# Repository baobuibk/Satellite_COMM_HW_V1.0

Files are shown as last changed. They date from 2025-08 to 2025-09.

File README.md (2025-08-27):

# Dự án COMM_BOARD - Satellite_COMM_HW_V1.0

## Giới thiệu
Dự án `COMM_BOARD` là một phần của hệ thống phần cứng giao tiếp vệ tinh (`Satellite_COMM_HW_V1.0`), được thiết kế trên **Altium Designer**. Bo mạch này hỗ trợ giao tiếp dữ liệu cho ứng dụng vệ tinh, bao gồm truyền nhận tín hiệu RF và giao tiếp với các thiết bị ngoại vi, sử dụng vi điều khiển STM32H745.

## Cấu trúc thư mục
```
├── 01_DESIGN/                # Tệp thiết kế chính
├── 02_Schematic_pdf/         # Sơ đồ mạch dưới dạng PDF
├── 03_BOM/                   # Danh sách linh kiện (Bill of Materials)
├── 04_GERBER/                # Tệp Gerber cho sản xuất
├── 05_SMT/                   # Hướng dẫn lắp ráp SMT
├── 06_CAD/                   # Tệp CAD bổ sung
├── 07_REF/                   # Tài liệu tham khảo
├── 08_3D/                    # Mô hình 3D
└── README.md                 # File này
```

## Yêu cầu
- **Phần mềm**: Altium Designer phiên bản 21.0 hoặc mới hơn.
- **Phần cứng**: 
  - Vi điều khiển STM32H745.
  - Các linh kiện khác theo BOM trong `03_BOM/`.
- **Công cụ khác**: Phần mềm lập trình firmware (STM32CubeIDE).

## Hướng dẫn cài đặt
1. **Tải dự án**:
   - Clone repository về máy:
     ```
     git clone https://github.com/baobuibk/Satellite_COMM_HW_V1.0.git
     ```
2. **Mở dự án trong Altium**:
   - Mở Altium Designer.
   - Chọn `File > Open Project` và điều hướng đến thư mục `1_COMM_BOARD`.
   - Mở tệp `.PrjPcb` trong thư mục.

## Hướng dẫn sản xuất
- Xuất Gerber từ thư mục `04_GERBER/` và gửi cho nhà sản xuất.
- Tham khảo `05_SMT/` để lắp ráp linh kiện.
- Kiểm tra thiết kế bằng DRC trong Altium trước khi sản xuất.

## Ghi chú
- Đảm bảo kiểm tra kết nối RF và nguồn điện trước khi sử dụng.
- Tài liệu tham khảo bổ sung có trong `07_REF/`.

## Liên hệ
- Tác giả: [baobuibk]
- GitHub: [https://github.com/baobuibk]

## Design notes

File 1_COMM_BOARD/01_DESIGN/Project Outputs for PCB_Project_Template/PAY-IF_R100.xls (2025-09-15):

Board Stack Report
Stack Up |  | Layer Stack
Layer | Board Layer Stack | Name | Material | Thickness | Constant
1 |  | Top Overlay |  | 0mm
2 |  | Top Solder | Solder Resist | 0.012mm | 3.5
3 |  | Top Layer |  | 0.055mm
4 |  | Dielectric 2 | FR-4 | 0.1mm | 3.9
5 |  | L2_GND | CF-004 | 0.032mm
6 |  | Dielectric 3 |  | 0.11mm | 4.1
7 |  | L3_PWR | CF-004 | 0.032mm
8 |  | Dielectric 1 | FR-4 | 0.94mm | 4.8
9 |  | L4_SIG | CF-004 | 0.032mm
10 |  | Dielectric 4 |  | 0.11mm | 4.1
11 |  | L5_GND | CF-004 | 0.032mm
12 |  | Dielectric 5 | FR-4 | 0.1mm | 3.9
13 |  | Bottom Layer |  | 0.055mm
14 |  | Bottom Solder | Solder Resist | 0.012mm | 3.5
15 |  | Bottom Overlay |  | 0mm
 | Height : 1.622mm

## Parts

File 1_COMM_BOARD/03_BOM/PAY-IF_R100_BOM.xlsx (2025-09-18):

Name | Description | Designator | Quantity | Footprint | Manufacturer | Manufacturer P/N
BT_NRST | SWITCH TACTILE SPST-NO 0.05A 12V | BT1 | 1 | SW2-SMD | C&K Components | PTS636SK25FSMTR LFS
0.1uF/16V | CAP CER 0.1UF 25V X7R 0603 | C1, C2, C3, C4, C5, C6, C7, C8, C9, C10, C11, C12, C13, C14, C15, C16, C17, C18, C19, C20, C21, C24, C27, C28, C30, C31, C32, C34, C58, C59, C60, C61, C62, C63, C64, C65, C66, C67, C68, C69, C71, C72, C73, C74, C75, C76, C77, C78, C79, C80, C90, C91, C94, C96, C97, C98, C99, C100, C101, C103 | 60 | CAP_C_1608X80 | Samsung Electro-Mechanics | CL10B104KA8NNNC
12pF/10V | CAP CER 12PF 50V C0G/NP0 0603 | C22, C23, C25, C26 | 4 | CAP_C_1608X80 | Samsung Electro-Mechanics | CL10C120JB81PNC
2.2uF/10V | CAP CER 2.2UF 10V X7R 0603 | C29, C46, C86, C87 | 4 | CAP_C_1608X80 | Samsung Electro-Mechanics | CL10B225KP8NNNC
1uF/25V | CAP CER 1UF 25V X7R 0603 | C33, C48, C50 | 3 | CAP_C_1608X80 | Samsung Electro-Mechanics | CL10B105KA8NNNC
4.7nF/16V | CAP CER 4700PF 50V X7R 0603 | C35 | 1 | CAP_C_1608X80 | Samsung Electro-Mechanics | CL10B472KB8NNNC
10uF/25V | CAP CER 10UF 25V X5R 0603 | C36, C38, C40, C41, C45, C49 | 6 | CAP_C_1608X80 | Samsung Electro-Mechanics | CL10A106MA8NRNC
1uF/16V | CAP CER 1UF 25V X7R 0603 | C37, C39, C93, C95 | 4 | CAP_C_1608X80 | Samsung Electro-Mechanics | CL10B105KA8NNNC
2.2nF/25V | CAP CER 2200PF 50V X7R 0603 | C42, C43 | 2 | CAP_C_1608X80 | Samsung Electro-Mechanics | CL10B222KB8NNNC
10nF/16V | CAP CER 10000PF 50V X7R 0603 | C44 | 1 | CAP_C_1608X80 | Samsung Electro-Mechanics | CL10B103KB8NNNC
4.7uF/16V | CAP CER 4.7UF 6.3V X7R 0603 | C47, C70, C88, C89, C92 | 5 | CAP_C_1608X80 | Samsung Electro-Mechanics | CL10B475KQ8NQNC
SS54 | DIODE SCHOTTKY 40V 5A SMA | D1 | 1 | DO-214AC_SMA | Multicomp | SS54
BLM18PG121SN1D | FERRITE BEAD 120 OHM 0603 1LN | FB2 | 1 | IND_1608x65 | Murata | BLM18PG121SN1D
ESQ-126-14-G-D | CONN SOCKET 52POS 0.1 GOLD PCB | H1, H2 | 2 | SAMTEC_ESQ-126-14-G-D | Samtec | ESQ-126-14-G-D
hole_space | x | Hole1, Hole2, Hole3, Hole4 | 4 | HOLE_SPACE | x | x
5040500591 | CONN HEADER SMD R/A 5POS 1.5MM | J1 | 1 | 5040500591 | Molex | 504050-0591
532610671 | CONN HEADER SMD R/A 6POS 1.25MM | J1B, J4B | 2 | MOLEX_532610671 | Molex | 53261-0671
5040500991 | CONN HEADER SMD R/A 9POS 1.5MM | J2, J3 | 2 | 5040500991 | Molex | 504050-0991
532610971 | CONN HEADER SMD R/A 9POS 1.25MM | J2B, J3B | 2 | 532610971 | Molex | 53261-0971
5040500691 | CONN HEADER SMD R/A 6POS 1.5MM | J4 | 1 | 5040500691 | Molex | 504050-0691
9159010061911 | CONN SSL RCP | J5 | 1 | 9159010061911 | x | x
61301021121 | CONN HEADER VERT 10POS 2.54MM | J5BK | 1 | 61301021121 | Wurth Elektronik | 61301021121
ZX62R-B-5P(30) | CONN RCPT USB2.0 MICRO B SMD R/A | J6 | 1 | AMPHENOL_GMCB05321121BEU | Hirose Electric Co Ltd | ZX62R-B-5P(30)
SRP7050TA-220M | FIXED IND 22UH 2.5A 170 MOHM SMD | L1 | 1 | SRP7050TA-220M | Bourns | SRP7050TA-220M
150060BS75000 | LED BLUE CLEAR 0603 SMD | LED1 | 1 | LED_0603 | Wurth Elektronik | 150060BS75000
150060GS75000 | LED GREEN CLEAR 0603 SMD | LED2 | 1 | LED_0603 | Wurth Elektronik | 150060GS75000
150060RS75000 | LED RED CLEAR 0603 SMD | LED3, LED4 | 2 | LED_0603 | Wurth Elektronik | 150060RS75000
150060YS75000 | LED YELLOW CLEAR 0603 SMD | LED5 | 1 | LED_0603 | Wurth Elektronik | 150060YS75000
MMBT2222A | BJT, SOT-23, 40V, 600mA, NPN, 0.25W, 150Â°C | Q1 | 1 | SOT95P240X120-3N | Nexperia | MMBT2222A,215
10k | RES SMD 10K OHM 1% 1/10W 0603 | R1, R2, R3, R4, R5, R6, R7, R8, R18, R22, R83, R84, R87, R91, R116, R117, R118, R127 | 18 | RES_C_1608X60 | Panasonic | ERJ-3EKF1002V
22R | RES SMD 22 OHM 1% 1/10W 0603 | R9, R10, R11, R12, R13, R14, R15, R16, R20, R21, R23, R24, R25, R26, R27, R28, R29, R30, R31, R32, R33, R34, R35, R36, R37, R38, R39, R40, R41, R42, R43, R44, R45, R46, R47, R48, R49, R50, R51, R52, R53, R54, R55, R56, R57, R58, R59, R60, R61, R62, R63, R64, R65, R66, R67, R68, R69, R70, R71, R72, R73, R74, R75, R76, R77, R78, R81, R85, R94, R95, R96, R97, R98, R99, R142, R143, R154, R155, R156, R157, R158, R159, R160, R163, R164, R165 | 86 | RES_C_1608X60 | Panasonic | ERJ-3EKF22R0V
47k | RES SMD 47K OHM 1% 1/10W 0603 | R17, R125 | 2 | RES_C_1608X60 | Panasonic | ERJ-3EKF4702V
0R | RES SMD 0 OHM JUMPER 1/10W 0603 | R19, R89, R90, R148, R150 | 5 | RES_C_1608X60 | Panasonic | ERJ-3GEY0R00V
1k | RES SMD 1K OHM 1% 1/10W 0603 | R79, R80, R88, R121, R126 | 5 | RES_C_1608X60 | Panasonic | ERJ-3EKF1001V
10k (DNP) | RES SMD 10K OHM 1% 1/10W 0603 | R82, R86 | 2 | RES_C_1608X60 | Panasonic | ERJ-3EKF1002V
100R (DNP) | RES SMD 100 OHM 1% 1/10W 0603 | R92, R93 | 2 | RES_C_1608X60 | Panasonic | ERJ-3EKF1000V
2.2k | RES SMD 2.2K OHM 1% 1/10W 0603 | R100 | 1 | RES_C_1608X60 | Panasonic | ERJ-3EKF2201V
60R | RES SMD 60.4 OHM 1% 1/10W 0603 | R114, R115 | 2 | RES_C_1608X60 | Panasonic | ERJ-3EKF60R4V
4.7k | RES SMD 4.7K OHM 1% 1/10W 0603 | R119, R151, R152, R153 | 4 | RES_C_1608X60 | Panasonic | ERJ-3EKF4701V
470k | RES SMD 470K OHM 1% 1/10W 0603 | R123 | 1 | RES_C_1608X60 | Panasonic | ERJ-3EKF4703V
11k | RES SMD 11K OHM 1% 1/10W 0603 | R124 | 1 | RES_C_1608X60 | Panasonic | ERJ-3EKF1102V
5.9k | RES SMD 5.9K OHM 1% 1/10W 0603 | R128 | 1 | RES_C_1608X60 | Panasonic | ERJ-3EKF5901V
16.5k | RES SMD 16.5K OHM 1% 1/10W 0603 | R161, R162 | 2 | RES_C_1608X60 | Panasonic | ERJ-3EKF1652V
JUMPER | x | SB1, SB2 | 2 | JUMPER_1608 | x | x
ESDCAN02-2BWY | TVS DIODE 26.5VWM 44VC SOT3233 | TVS2 | 1 | SOT323-3L_STM | STMicroelectronics | ESDCAN02-2BWY
STM32H745XIH6 | IC MCU 32BIT 2MB FLASH TFBGA | U1 | 1 | BGA265C80P17X17_1400X1400X110N | STMicroelectronics | STM32H745XIH6
IS42S32400J-6BL | DRAM 128M, 3.3V, SDRAM, 4Mx32, 166Mhz, 90 ball BGA (8mmx13mm) RoHS | U2 | 1 | BGA90C80P9X15_800X1300X120 | ISSI | IS42S32400J-6BL
MTFC32GAZAQDW-AAT | IC FLASH 32GBIT PAR 100LBGA | U3 | 1 | BGA_100_C_100P_10X17_1400X1800X150 | Micron | MTFC32GAZAQDW-AAT
AS3004204-0108X0PSAY | MRAM Avalanche High Performance Serial P-SRAM 4Mb in SOIC8 package with QSPI - 108MHz interface, 3V, -40 C to 105 C | U4 | 1 | SOIC127P790X216-8N | Avalanche Technology | AS3004204-0108X0PSAY
SN65HVD230DR | IC TRANSCEIVER HALF 1/1 8SOIC | U5 | 1 | SOIC127P599X175-8N | Texas Instruments | SN65HVD230DR
DS90LV011AQ-Q1 | LVDS Interface IC Automotive LVDS diff erential driver | U6, U7 | 2 | DS90LV011AQ-Q1 | Texas Instruments | DS90LV011AQMFE/NOPB
TPS259470ARPWR | IC ELECTRONIC FUSE 10VQFN | U9 | 1 | VQFN-HR-10 | Texas Instruments | TPS259470ARPWR
TPS5430DDAR | IC REG BUCK ADJ 3A 8SOPWR | U10 | 1 | CONV_TPS5430DDAR | Texas Instruments | TPS5430DDAR
IS66WVS4M8BLL-104NLI | IC PSRAM 32MBIT SPI QPI 8SOIC | U14 | 1 | SOIC8_150MIL_N_ISI | ISSI | IS66WVS4M8BLL-104NLI
TPL5010DDCR | IC OSC PROG TIMER TSOT23-6 | U15 | 1 | TPL5010DDCR | Texas Instruments | TPL5010DDCR
TC1047AVNBTR | SENSOR ANALOG -40C-125C SOT23-3 | U16, U17, U18 | 3 | SOT-23_MC_MCH | Microchip | TC1047AVNBTR
ECS-250-12-33Q-JES-TR | CRYSTAL 25.0000MHZ 12PF SMD | X1 | 1 | XTAL_ECS-250-12-33Q-JES-TR | ECS International | ECS-250-12-33Q-JES-TR
XT1312HHRXX32K76E | CRYSTAL, 3.2X1.5MM, 12.5PF LOAD | X2 | 1 | XT1312HHRXX32K76E | Vishay | XT1312HHRXX32K76E
 |  |  | 268

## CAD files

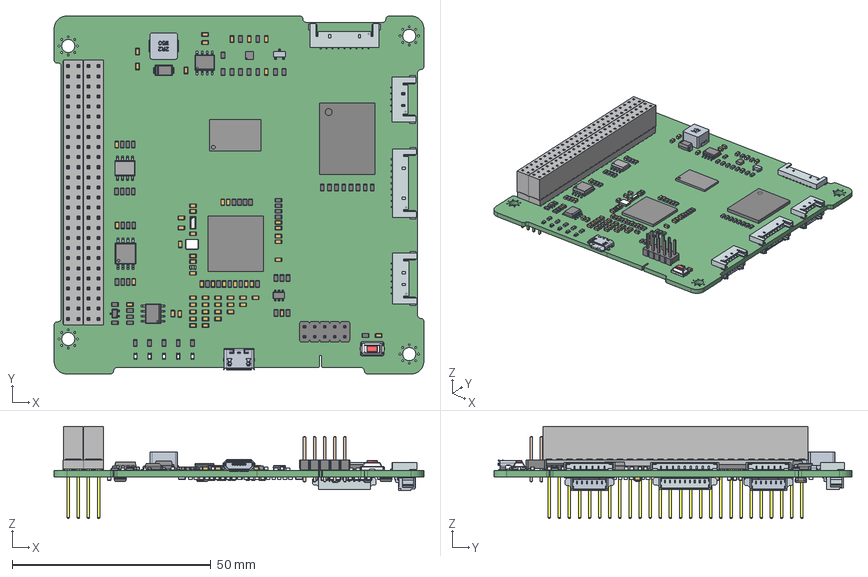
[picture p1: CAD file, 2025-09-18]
1_COMM_BOARD/08_3D/PAY-IF_R100.step
93.0 x 90.0 x 23.2 mm
Mid Body x 132
Mark x 132
housing x 5
cover x 5
base x 10
Polarity Mark x 5
ball x 170
PinsArrayLR
ESQ-126-14-G-D_socket x 2
ESQ-126-14-G-D_pins x 2
ESQ-126-14-G-D2_pins x 2
ESQ-126-14-G-D-LL_bpins x 2
6130xx21121_PIN x 10
XT1312HHRXX32K76E
TPS259470ARPWR
A1
A2
A3
A7
A8
A9
B1
B2
B3
B7
B8
B9
C1
C2
C3
C7
C8
C9
D1
D2
D3
D7
D8
D9
E1
E2
E3
E7
E8
E9
F1
F2
F3
F7
F8
F9
G1
G2
G3
G7
G8
G9
H1
H2
H3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

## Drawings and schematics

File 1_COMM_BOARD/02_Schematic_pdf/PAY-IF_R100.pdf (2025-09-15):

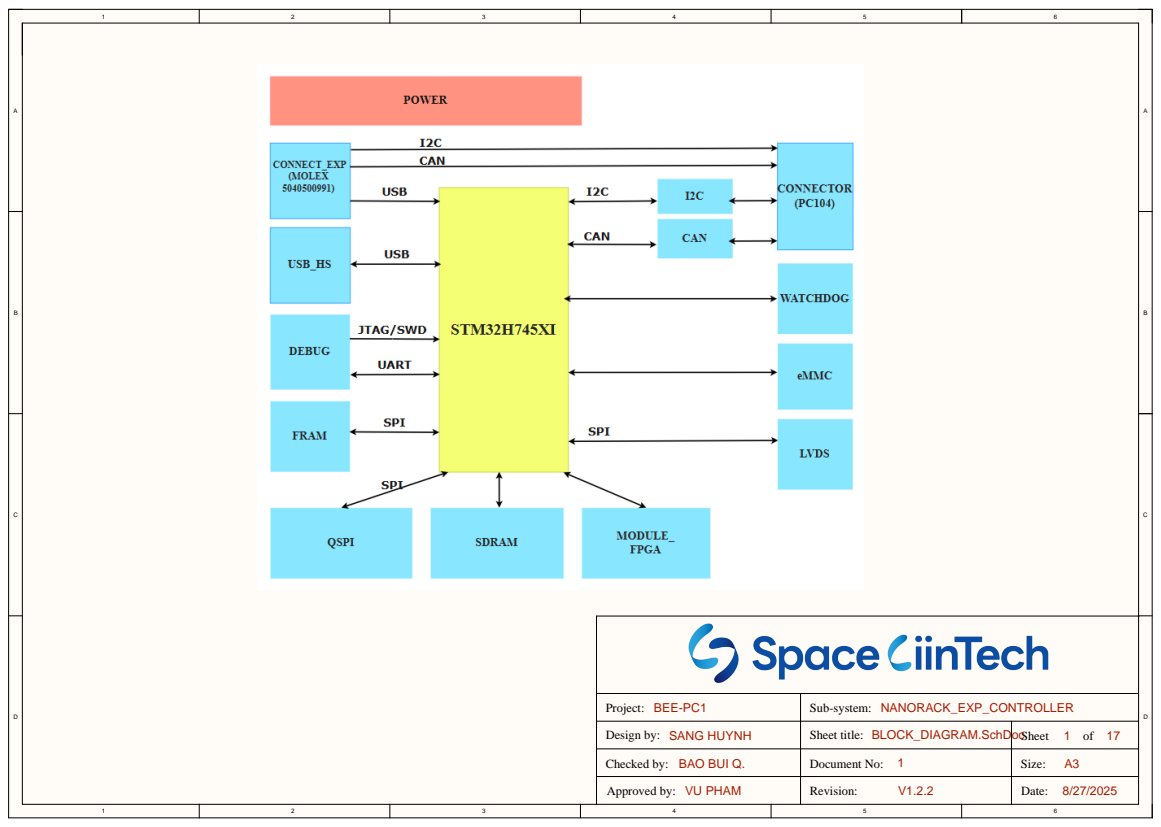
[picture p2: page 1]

Project: BEE-PC1 | Sub-system: NANORACK_EXP_CONTROLLER

Design by: SANG HUYNH | Sheet title: BLOCK_DIAGRAM.SchDoc | Sheet 1 of 17

Checked by: BAO BUI Q. | Document No: 1 | Size: A3

Approved by: VU PHAM | V1.2.2 Revision: | Date: 8/27/2025

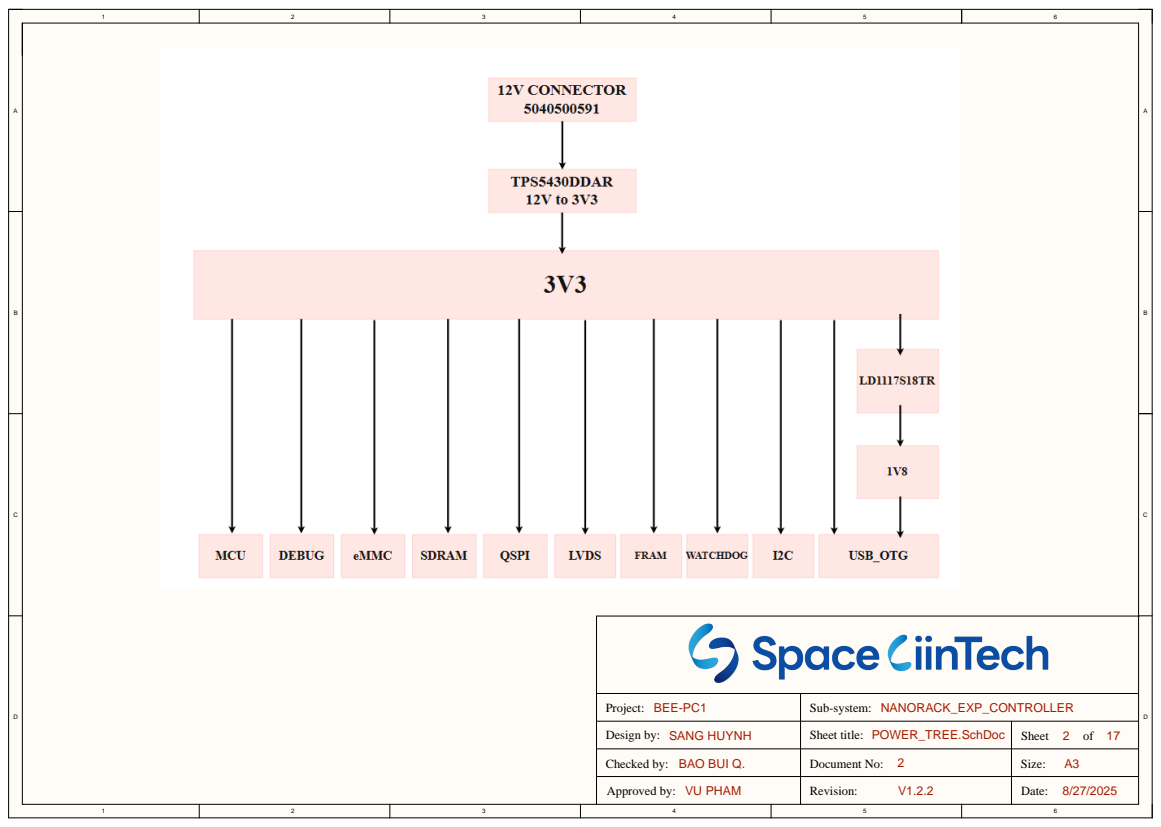
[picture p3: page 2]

Project: BEE-PC1 | Sub-system: NANORACK_EXP_CONTROLLER

Design by: SANG HUYNH | Sheet title: POWER_TREE.SchDoc | Sheet 2 of 17

Checked by: BAO BUI Q. | Document No: 2 | Size: A3

Date: 8/27/2025

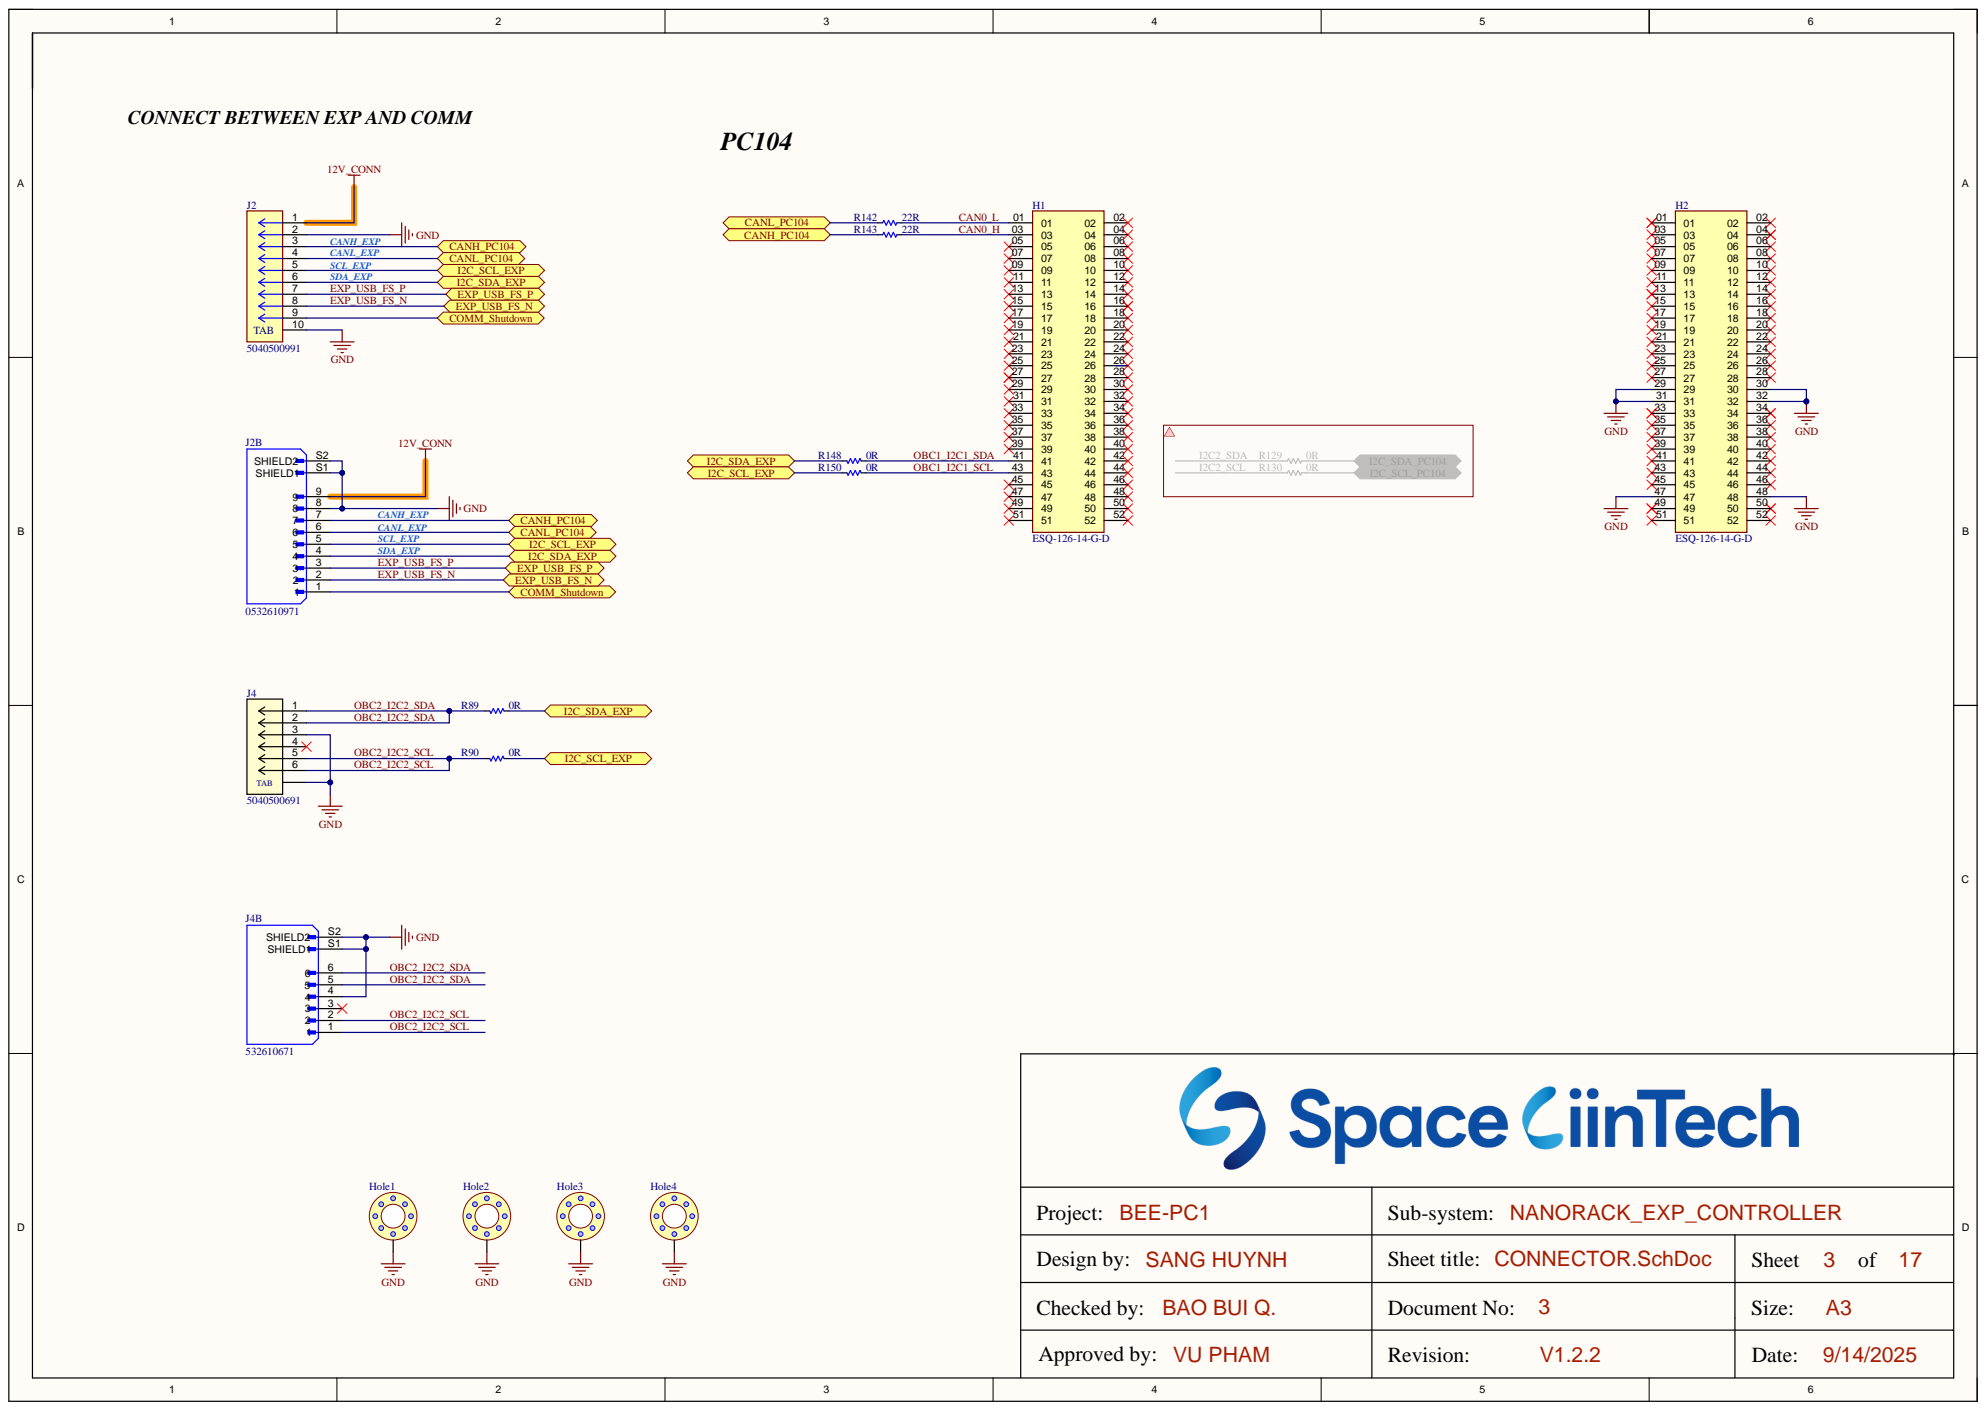
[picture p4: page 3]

CONNECT BETWEEN EXP AND COMM

Project: BEE-PC1 | Sub-system: NANORACK_EXP_CONTROLLER

Design by: SANG HUYNH | Sheet title: CONNECTOR.SchDoc | Sheet 3 of 17

Checked by: BAO BUI Q. | Document No: 3 | Size: A3

Date: 9/14/2025

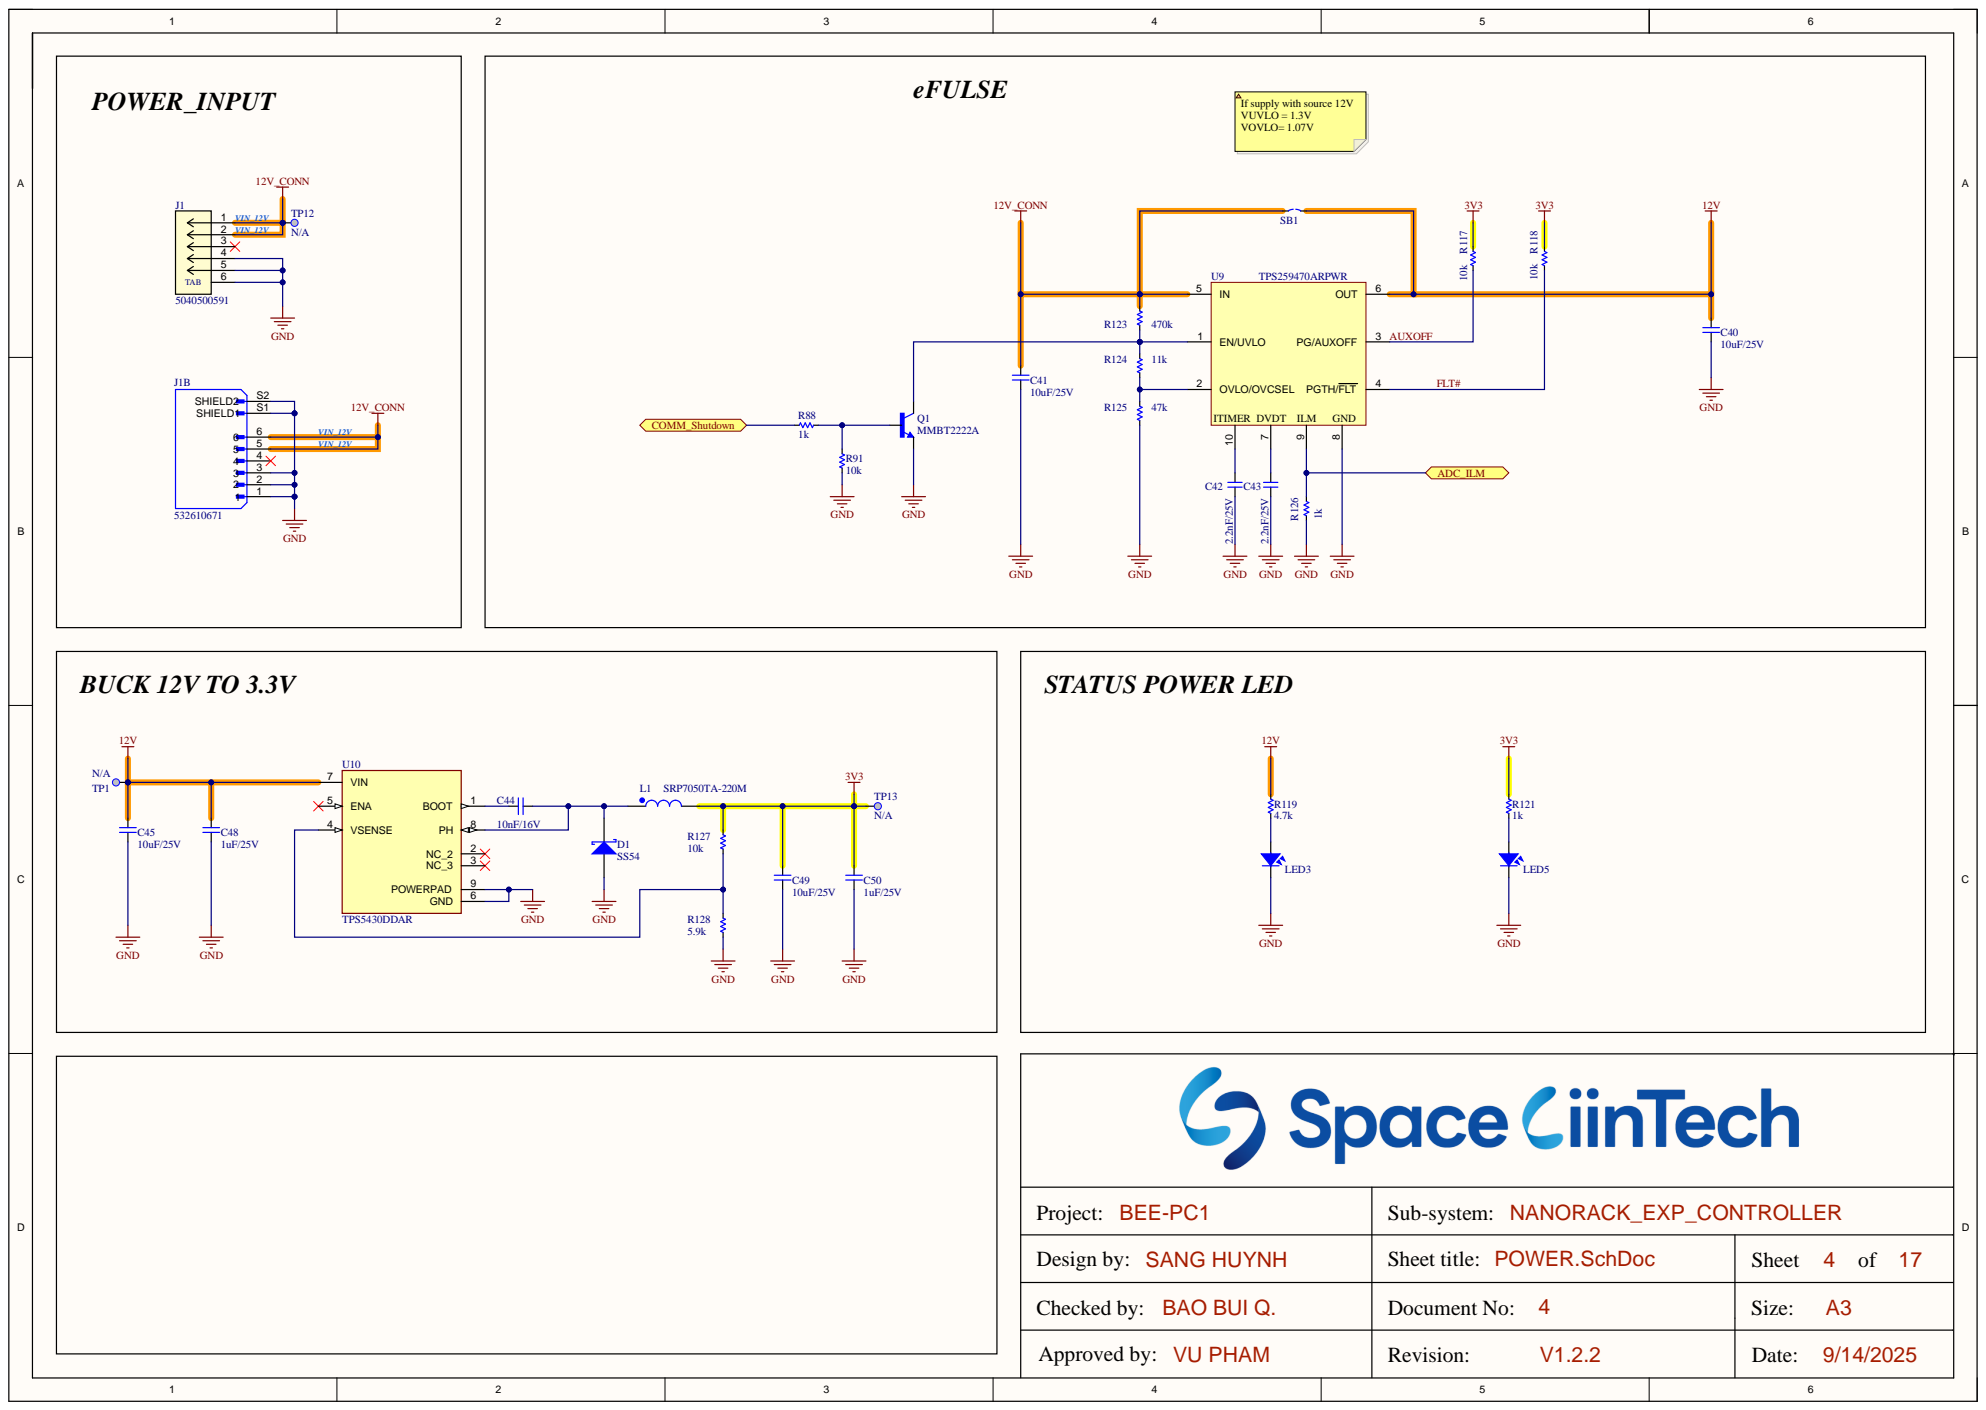
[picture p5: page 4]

If supply with source 12V
VUVLO = 1.3V
VOVLO= 1.07V

Project: BEE-PC1 | Sub-system: NANORACK_EXP_CONTROLLER

Design by: SANG HUYNH | Sheet title: POWER.SchDoc | Sheet 4 of 17

Checked by: BAO BUI Q. | Document No: 4 | Size: A3

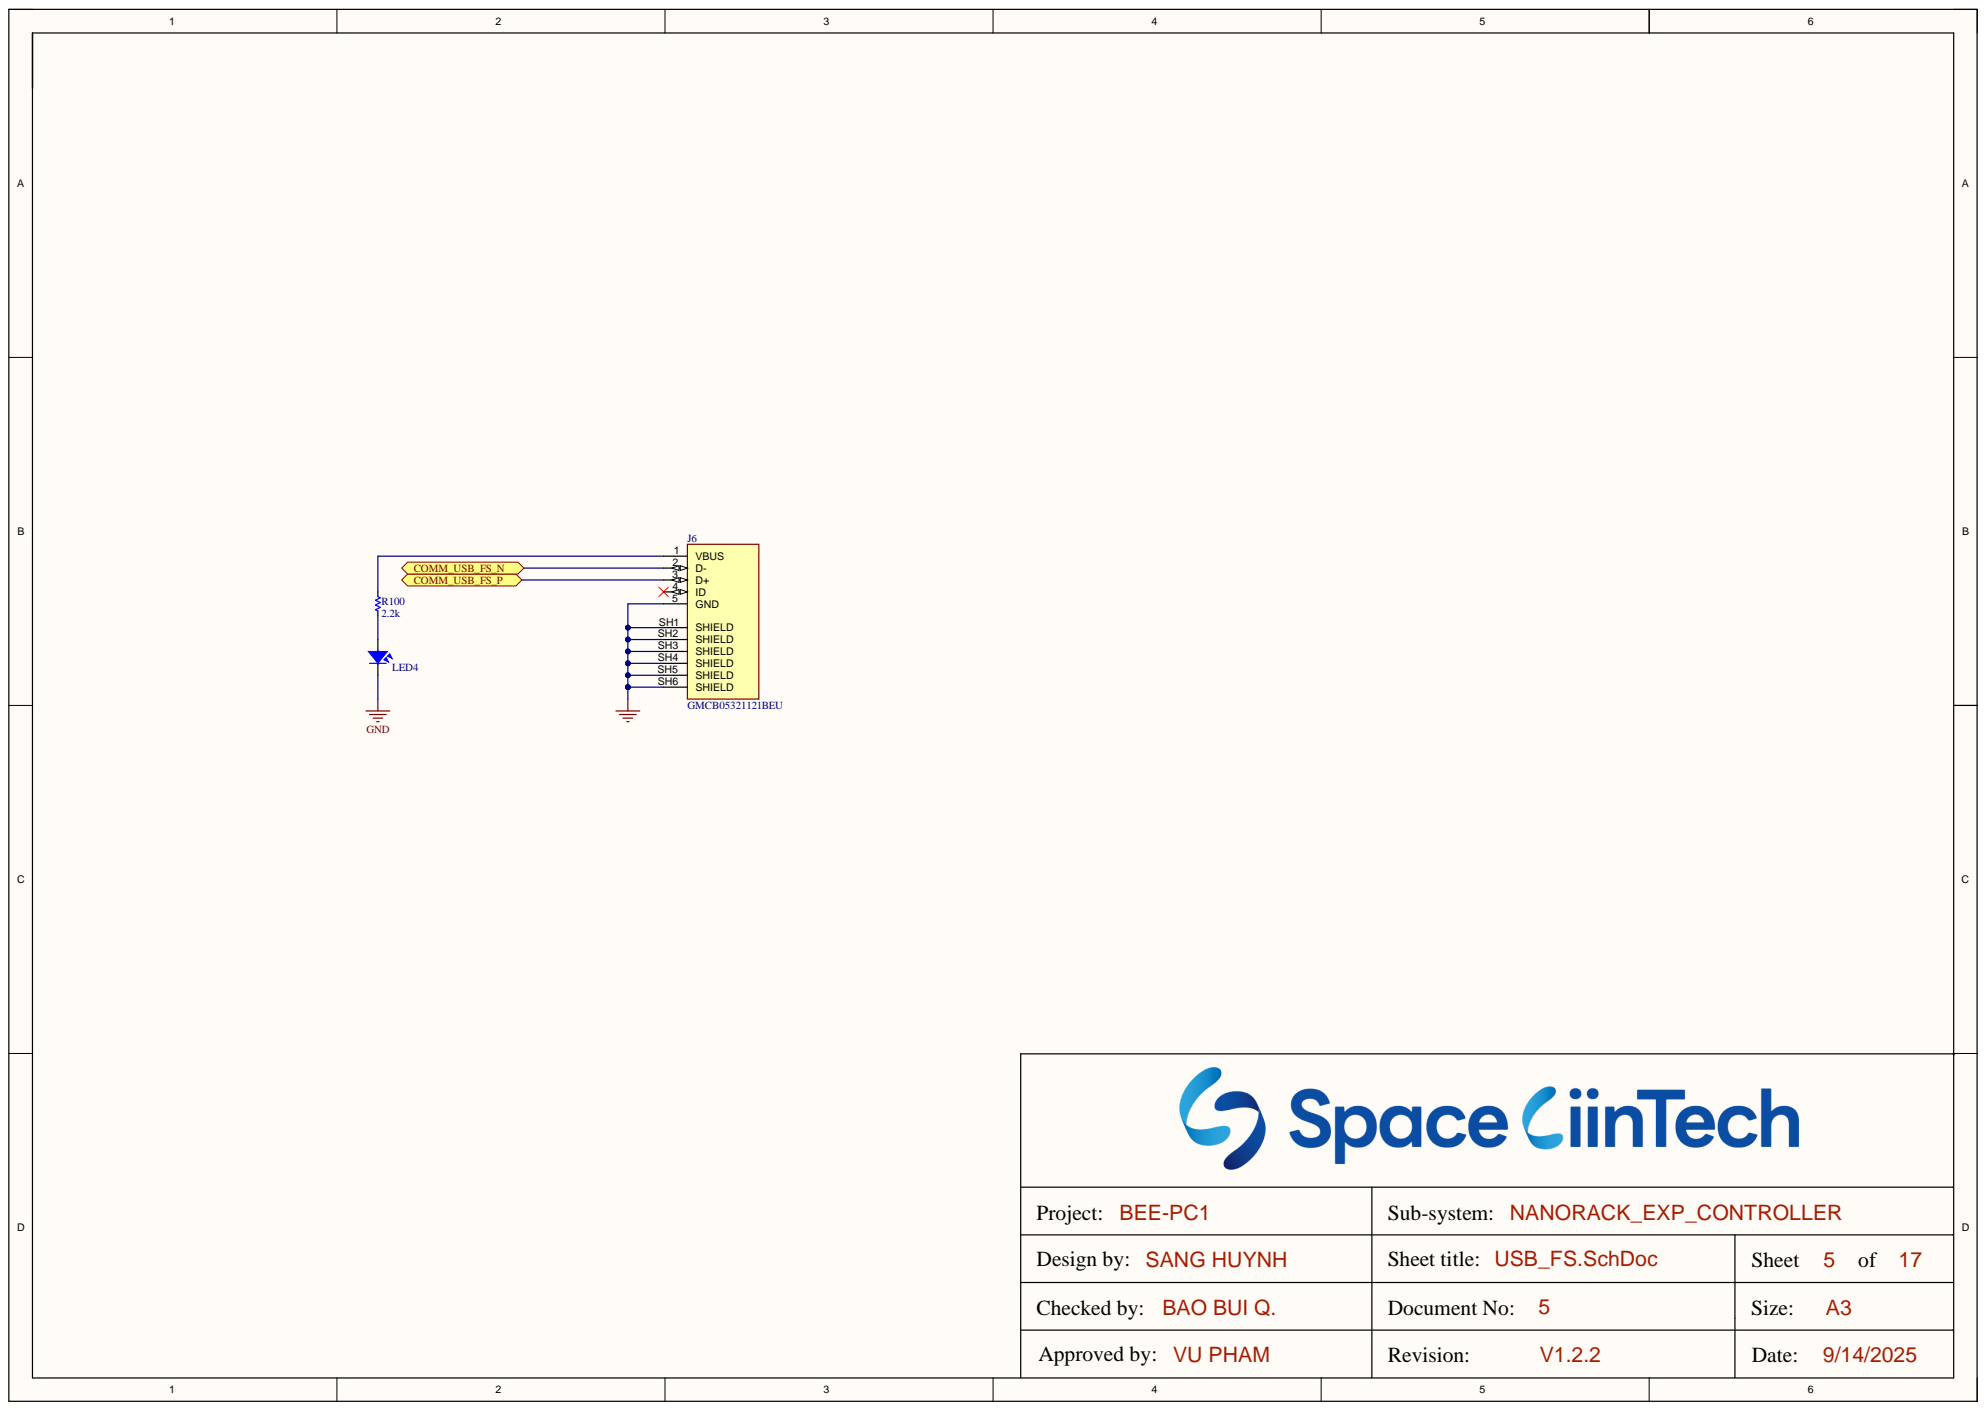
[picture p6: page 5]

Project: BEE-PC1 | Sub-system: NANORACK_EXP_CONTROLLER

Design by: SANG HUYNH | Sheet title: USB_FS.SchDoc | Sheet 5 of 17

Checked by: BAO BUI Q. | Document No: 5 | Size: A3

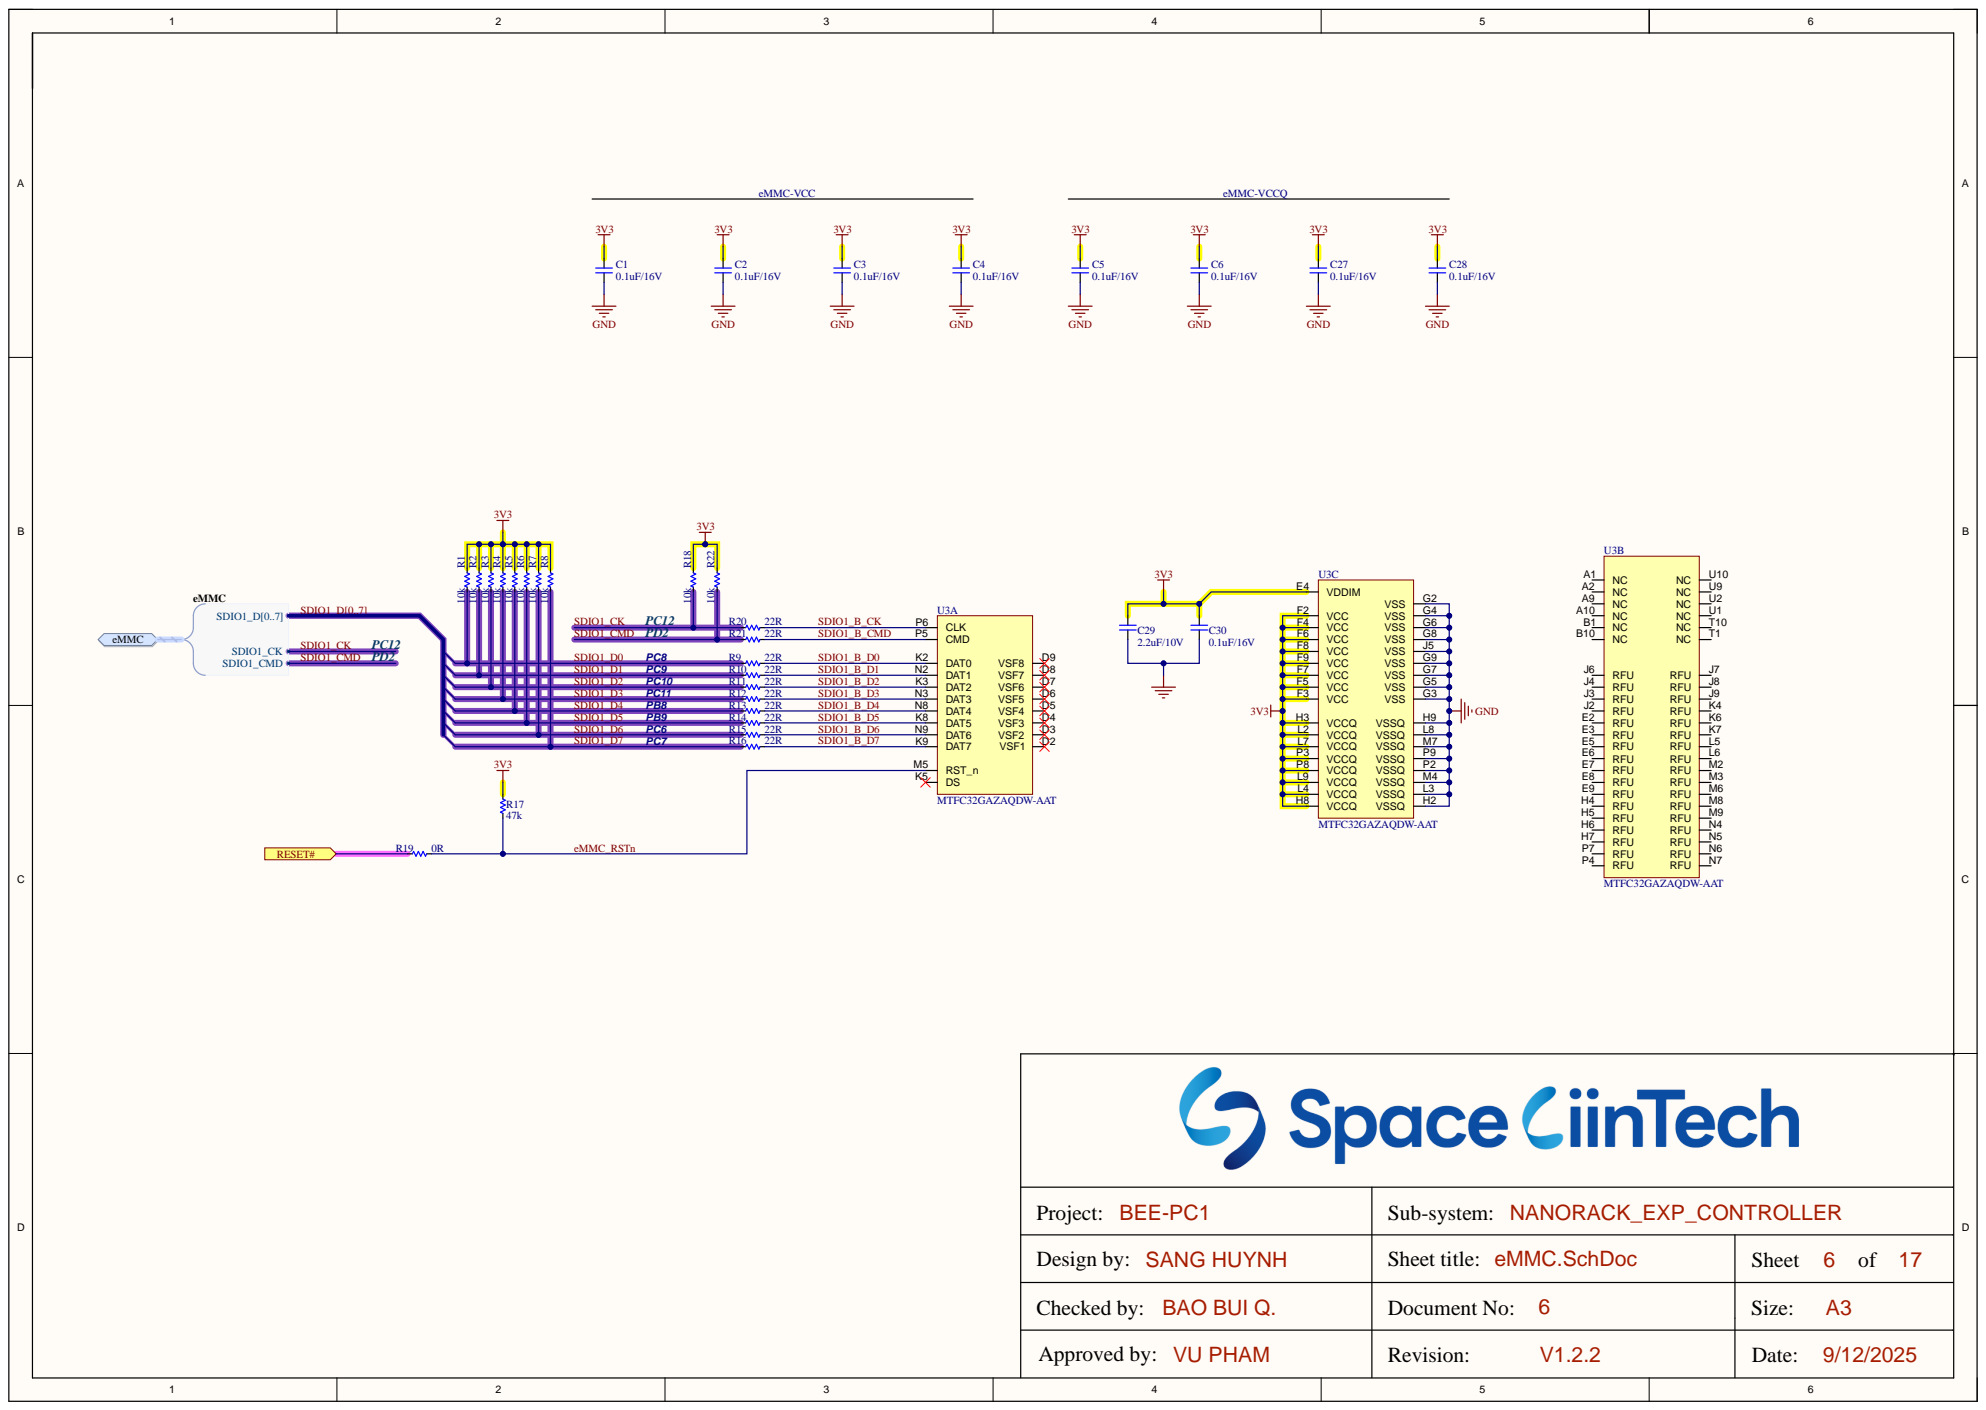
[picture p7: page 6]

Project: BEE-PC1 | Sub-system: NANORACK_EXP_CONTROLLER

Design by: SANG HUYNH | Sheet title: eMMC.SchDoc | Sheet 6 of 17

Checked by: BAO BUI Q. | Document No: 6 | Size: A3

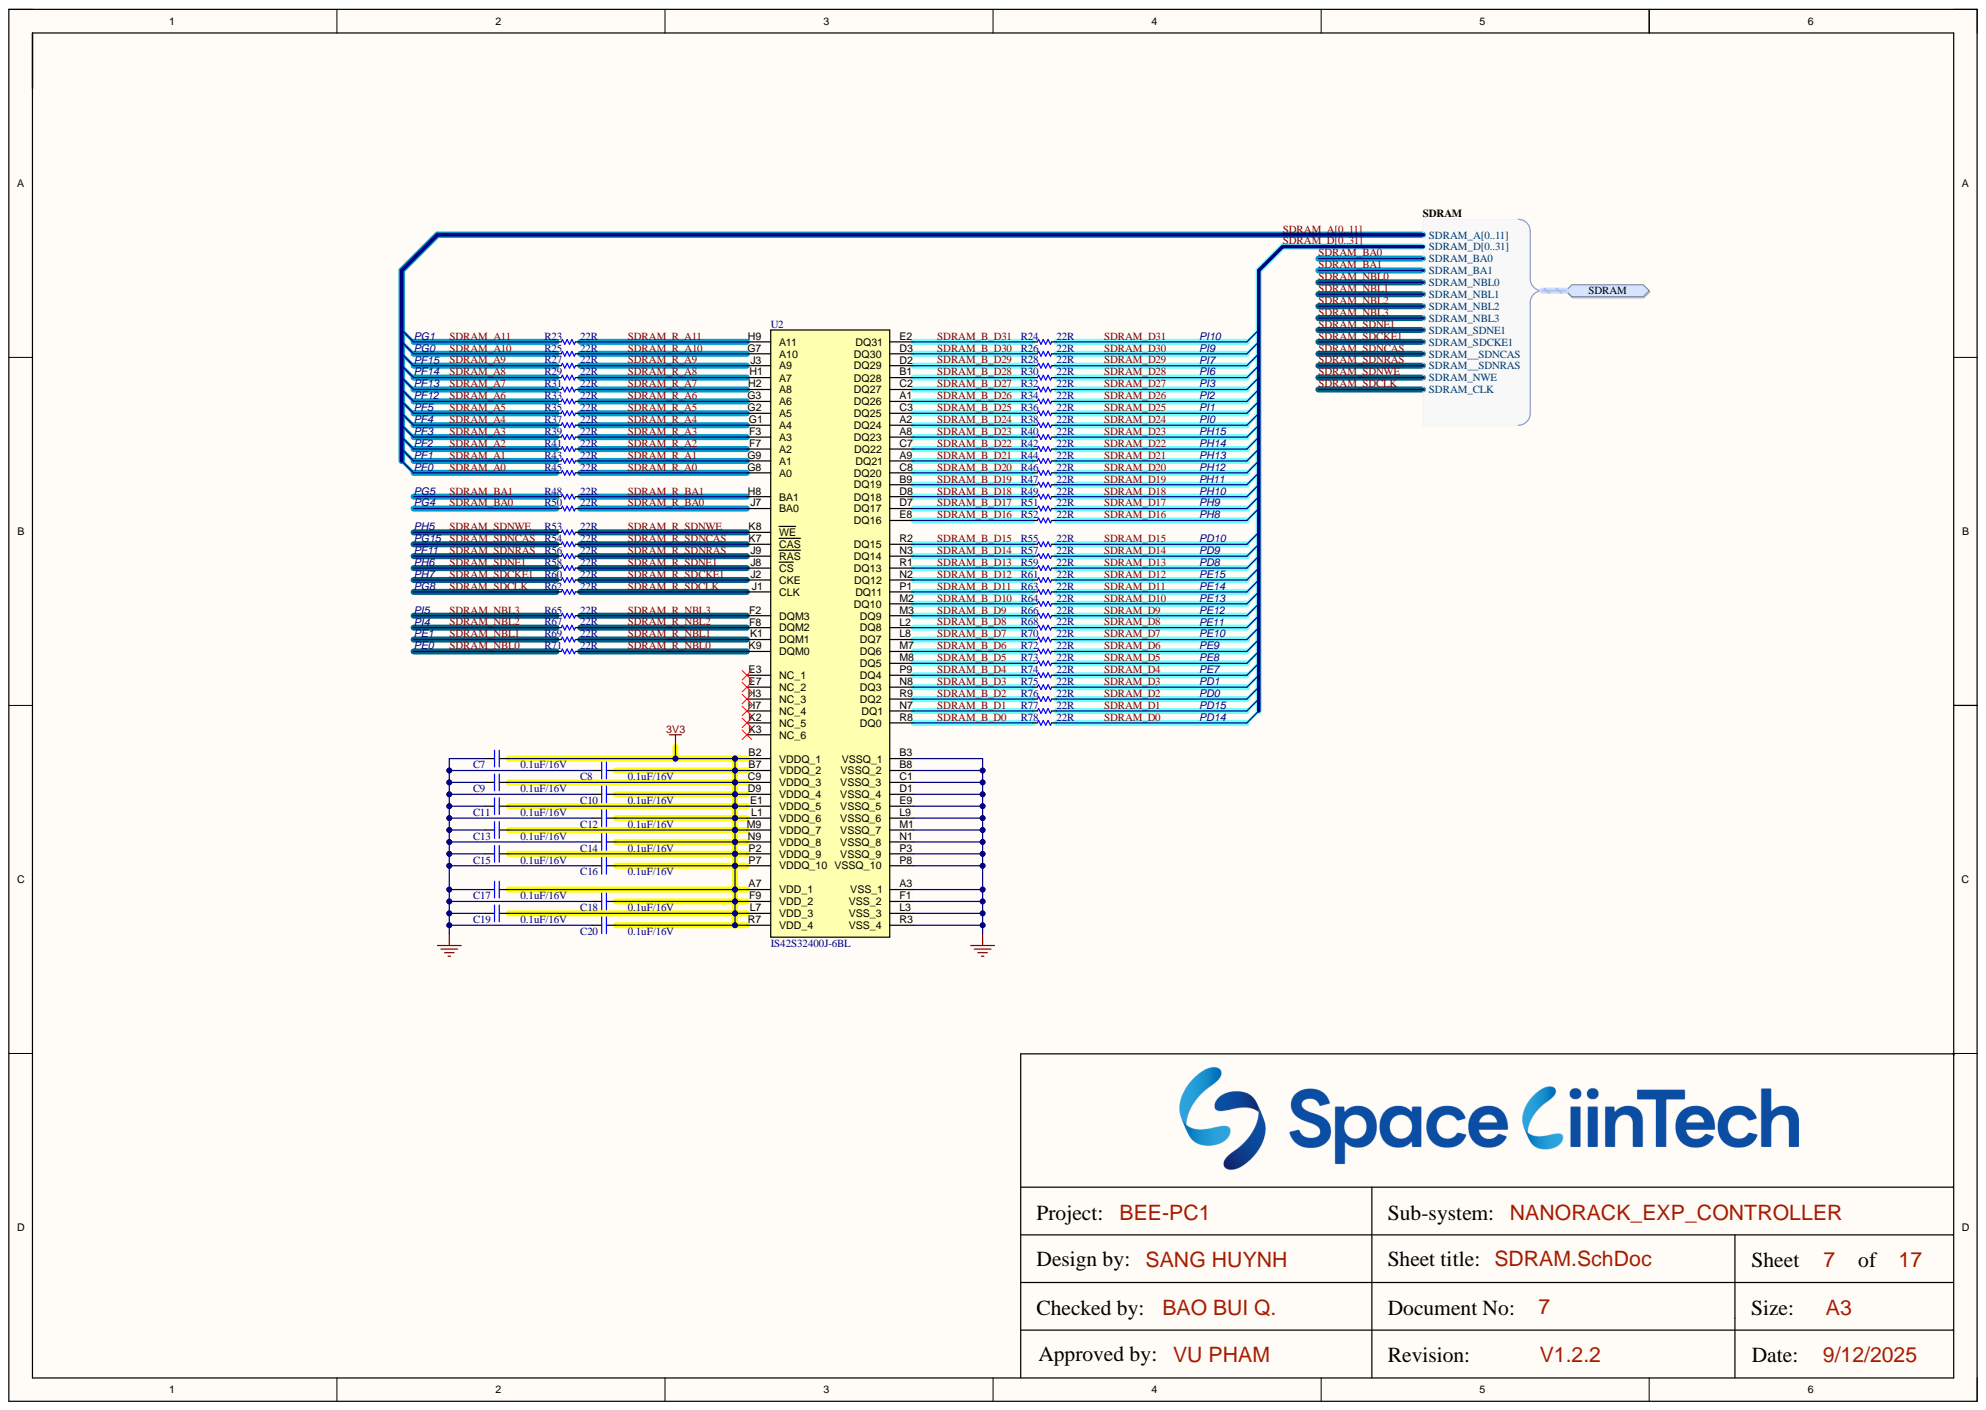
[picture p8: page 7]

Project : BEE-PC1 | Sub-system : NANORACK_EXP_CONTROLLER

Design by: SANG HUYNH | Sheet title: SDRAM.SchDoc | Sheet 7 of 17

Checked by: BAO BUI Q. | Document No: V1.2.2 7 | Size: A3

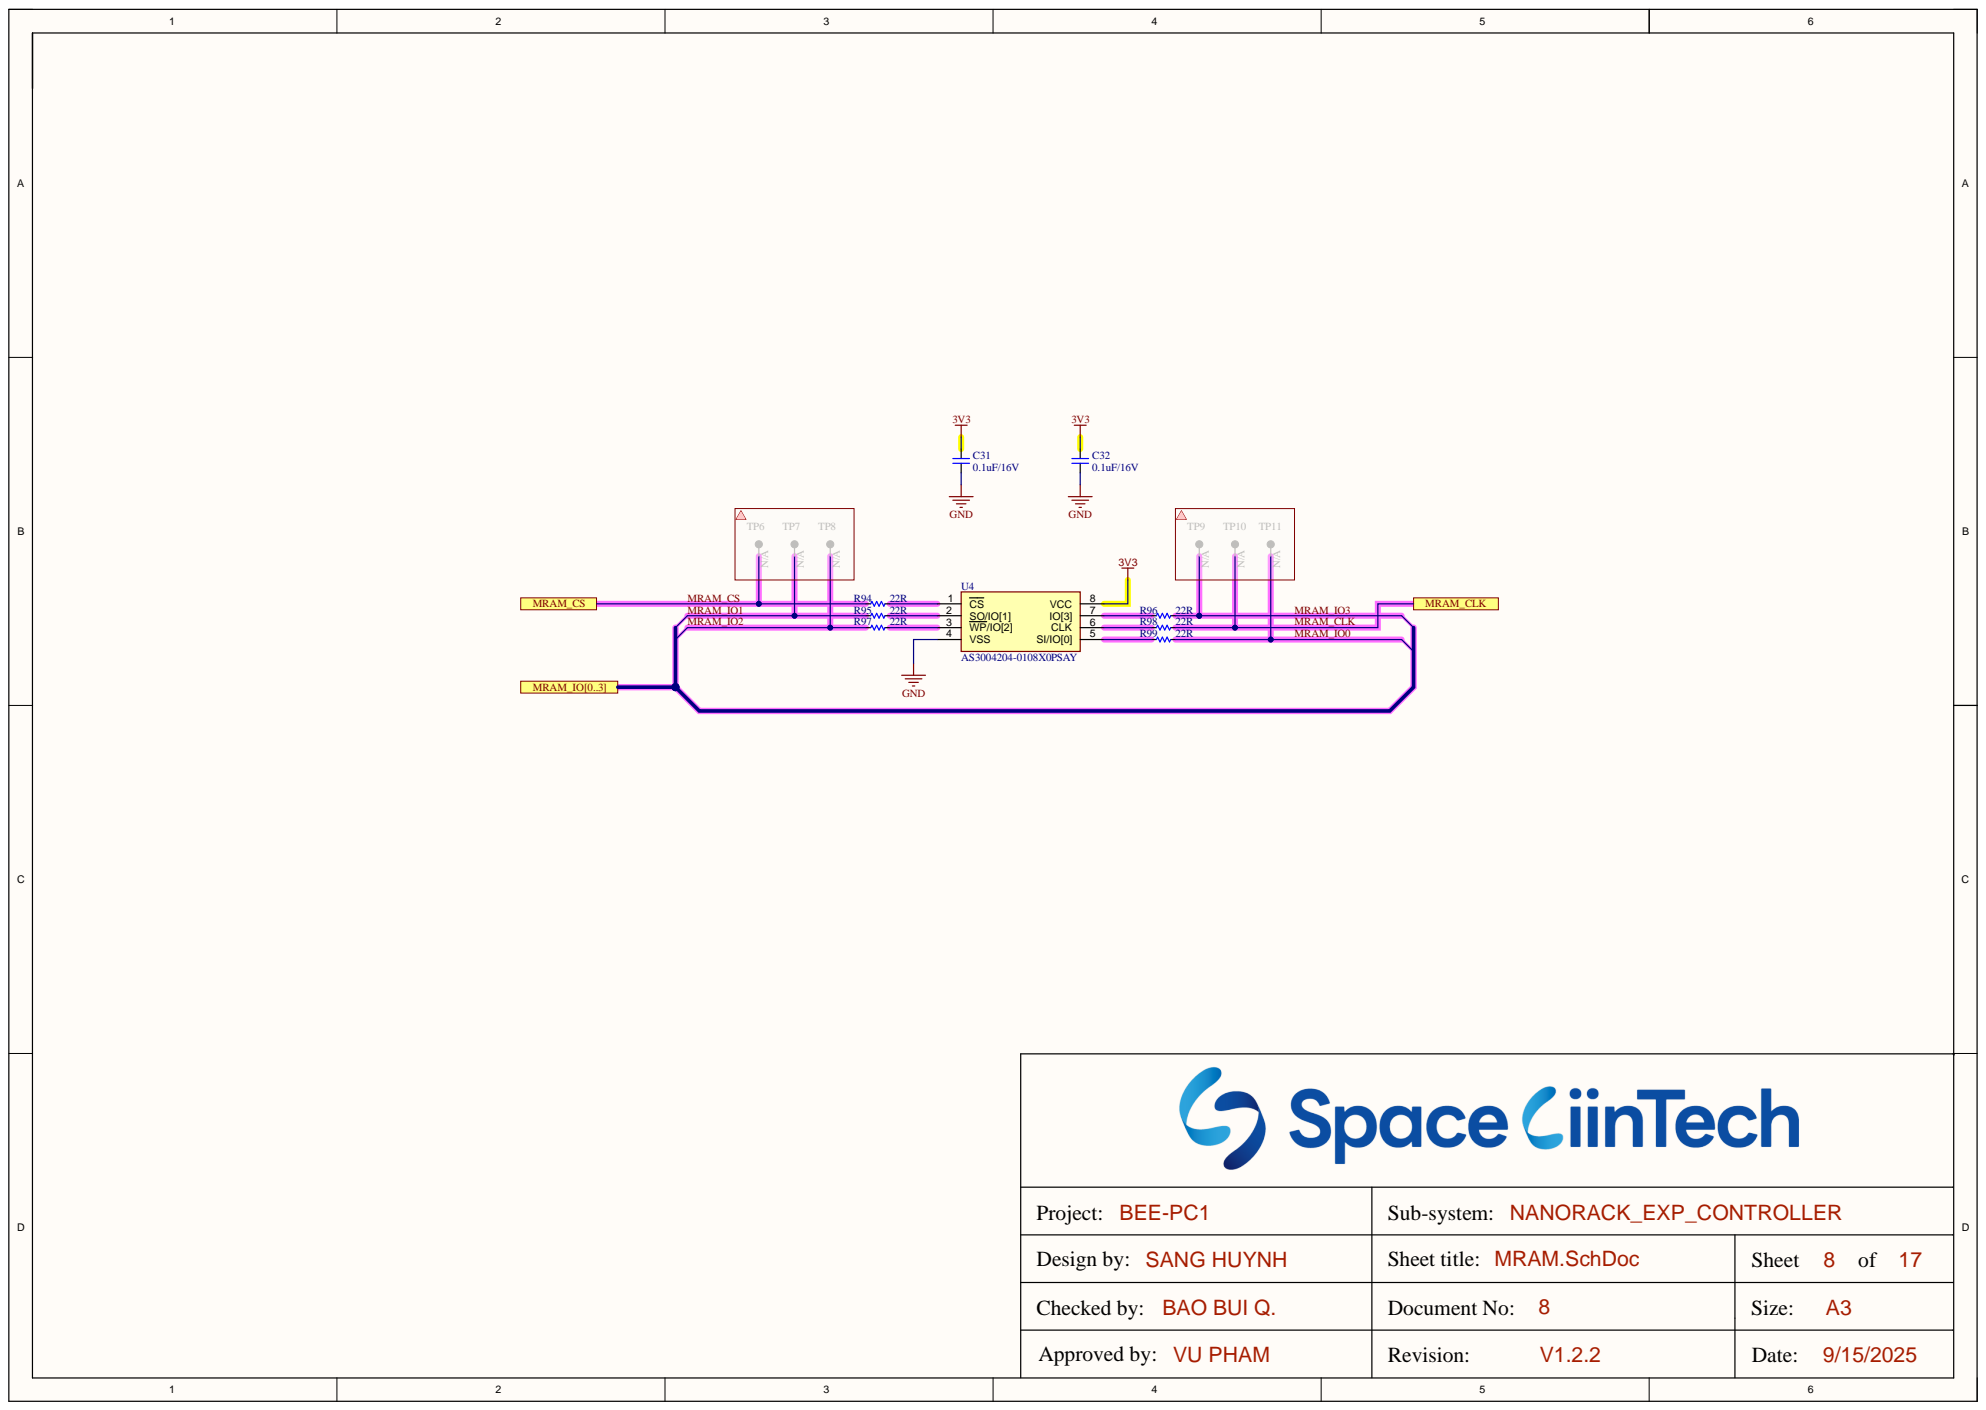
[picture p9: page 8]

Project: BEE-PC1 | Sub-system: NANORACK_EXP_CONTROLLER

Design by: SANG HUYNH | Sheet title: MRAM.SchDoc | Sheet 8 of 17

Checked by: BAO BUI Q. | Document No: 8 | Size: A3

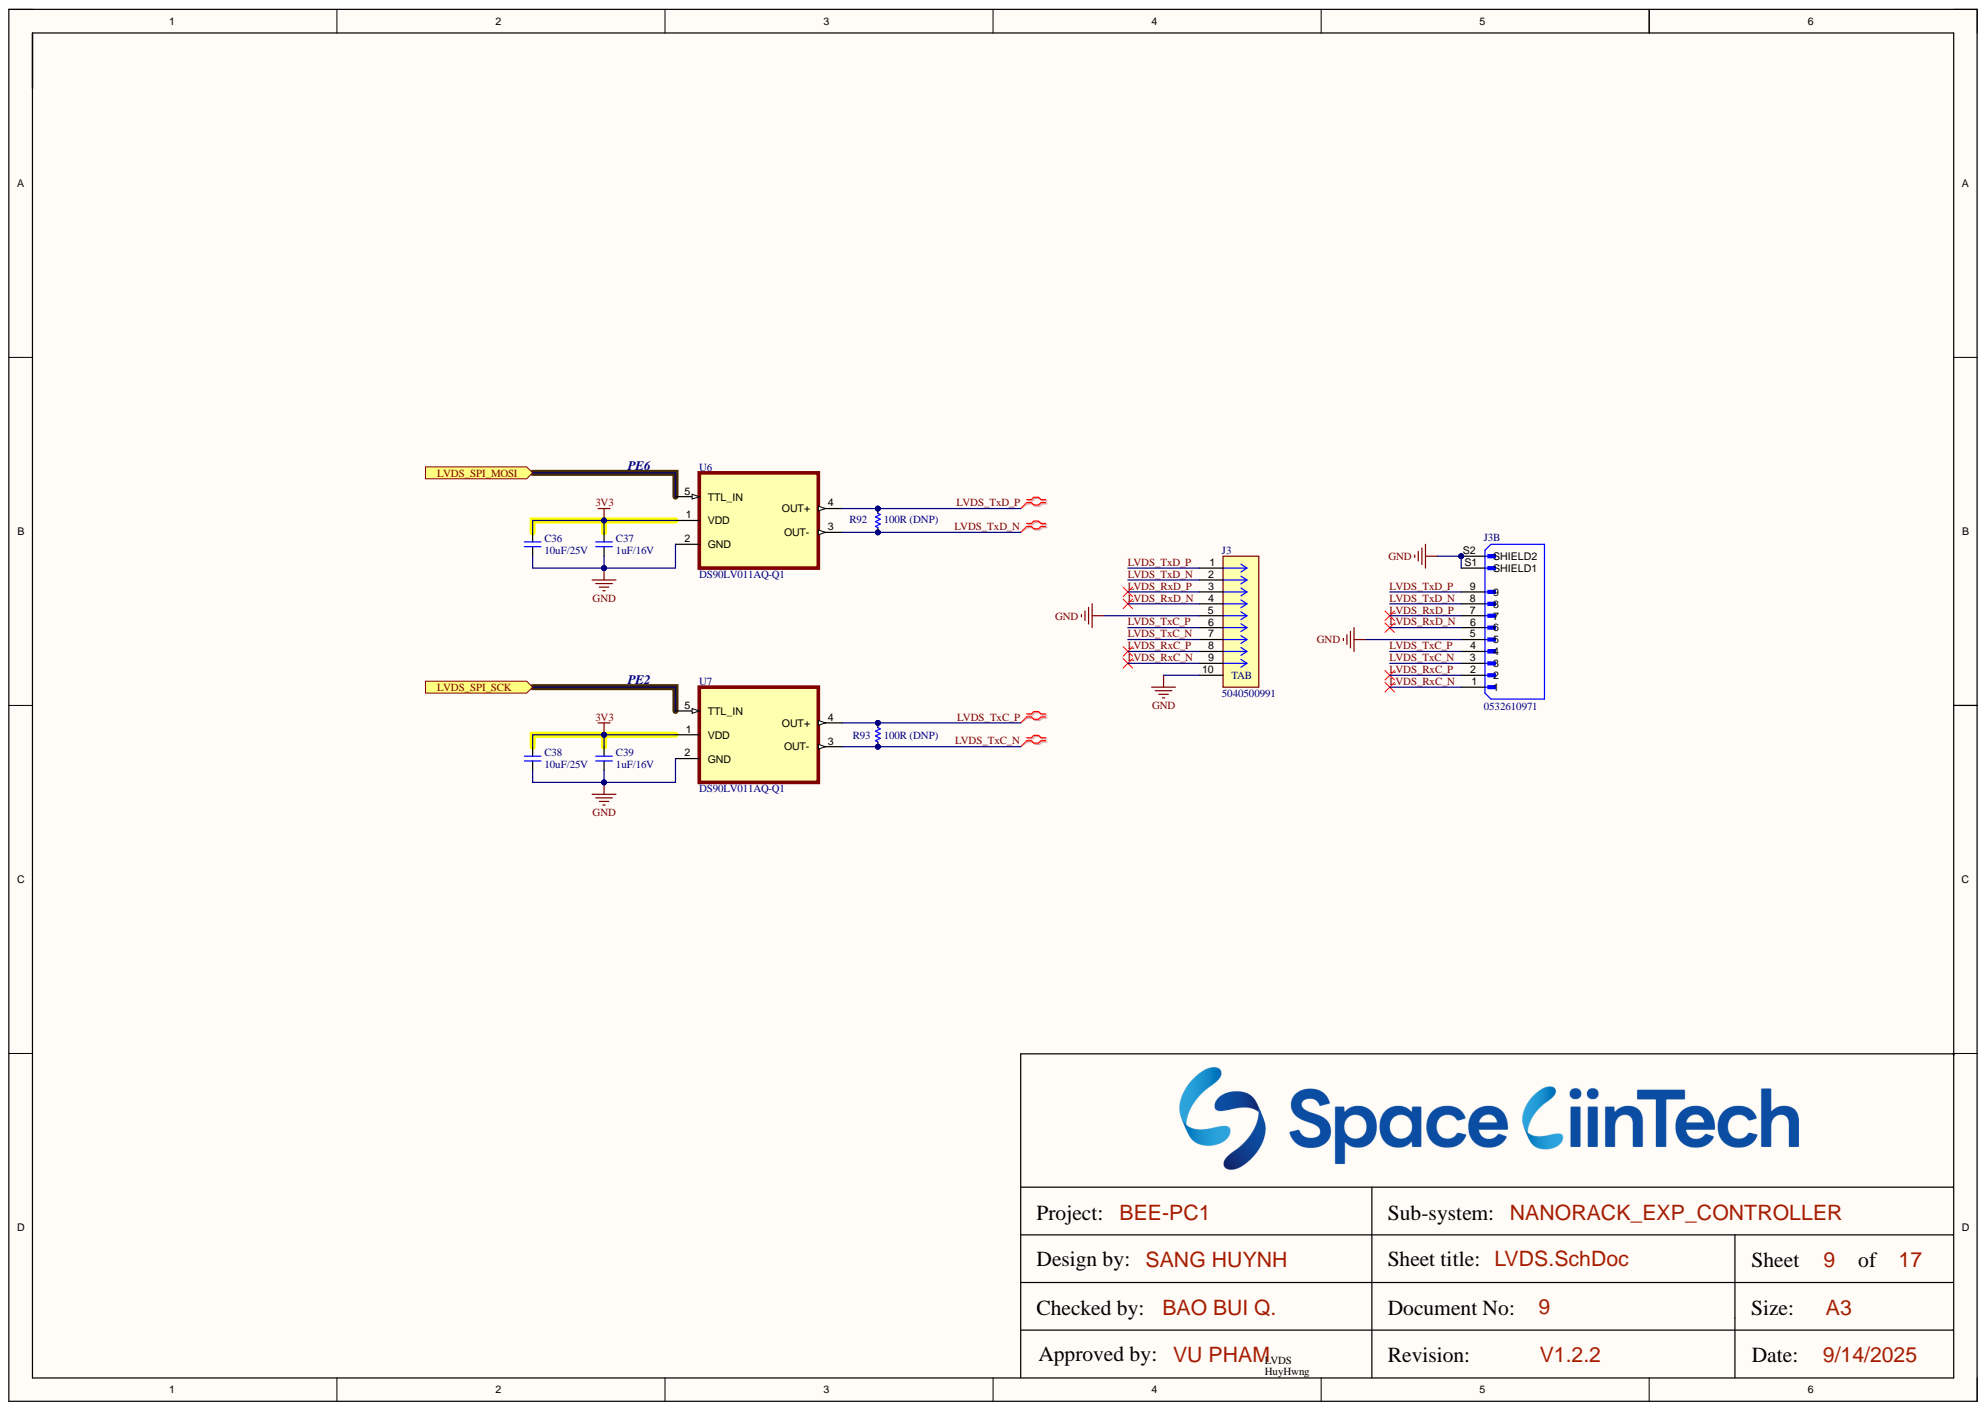
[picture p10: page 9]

Project : BEE-PC1 | Sub-system : NANORACK_EXP_CONTROLLER

Design by: SANG HUYNH | Sheet title: LVDS.SchDoc | Sheet 9 of 17

Checked by: BAO BUI Q. | Document No: V1.2.2 9 | Size: A3

LV D S HuyHw n g

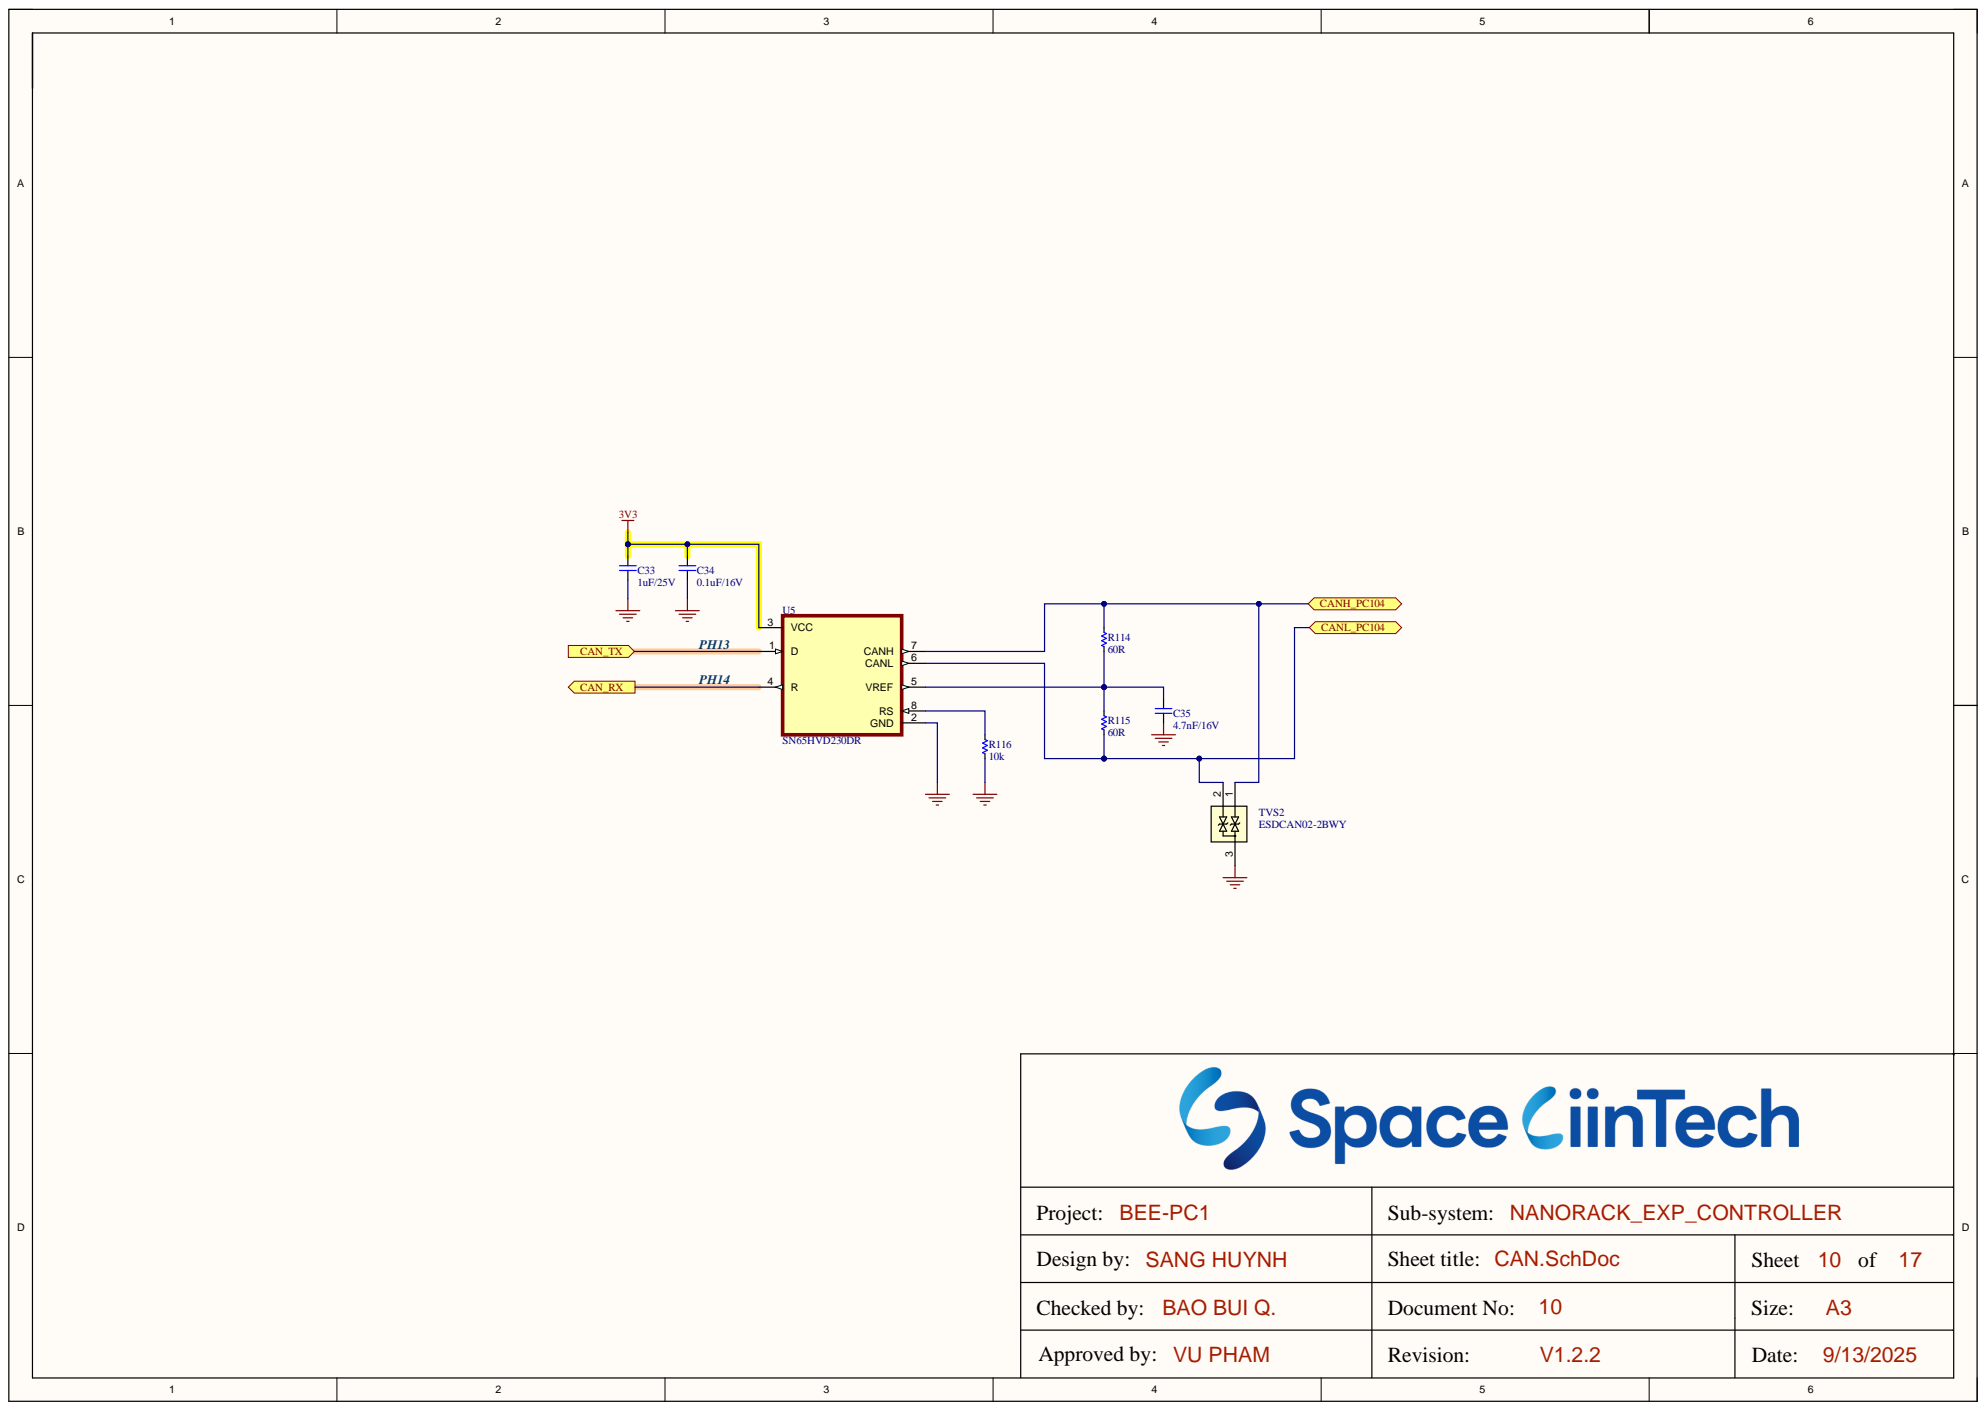
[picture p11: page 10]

Project : BEE-PC1 | Sub-system : NANORACK_EXP_CONTROLLER

Design by: SANG HUYNH | Sheet title: CAN.SchDoc | Sheet 10 of 17

Checked by: BAO BUI Q. | Document No: 10 | Size: A3

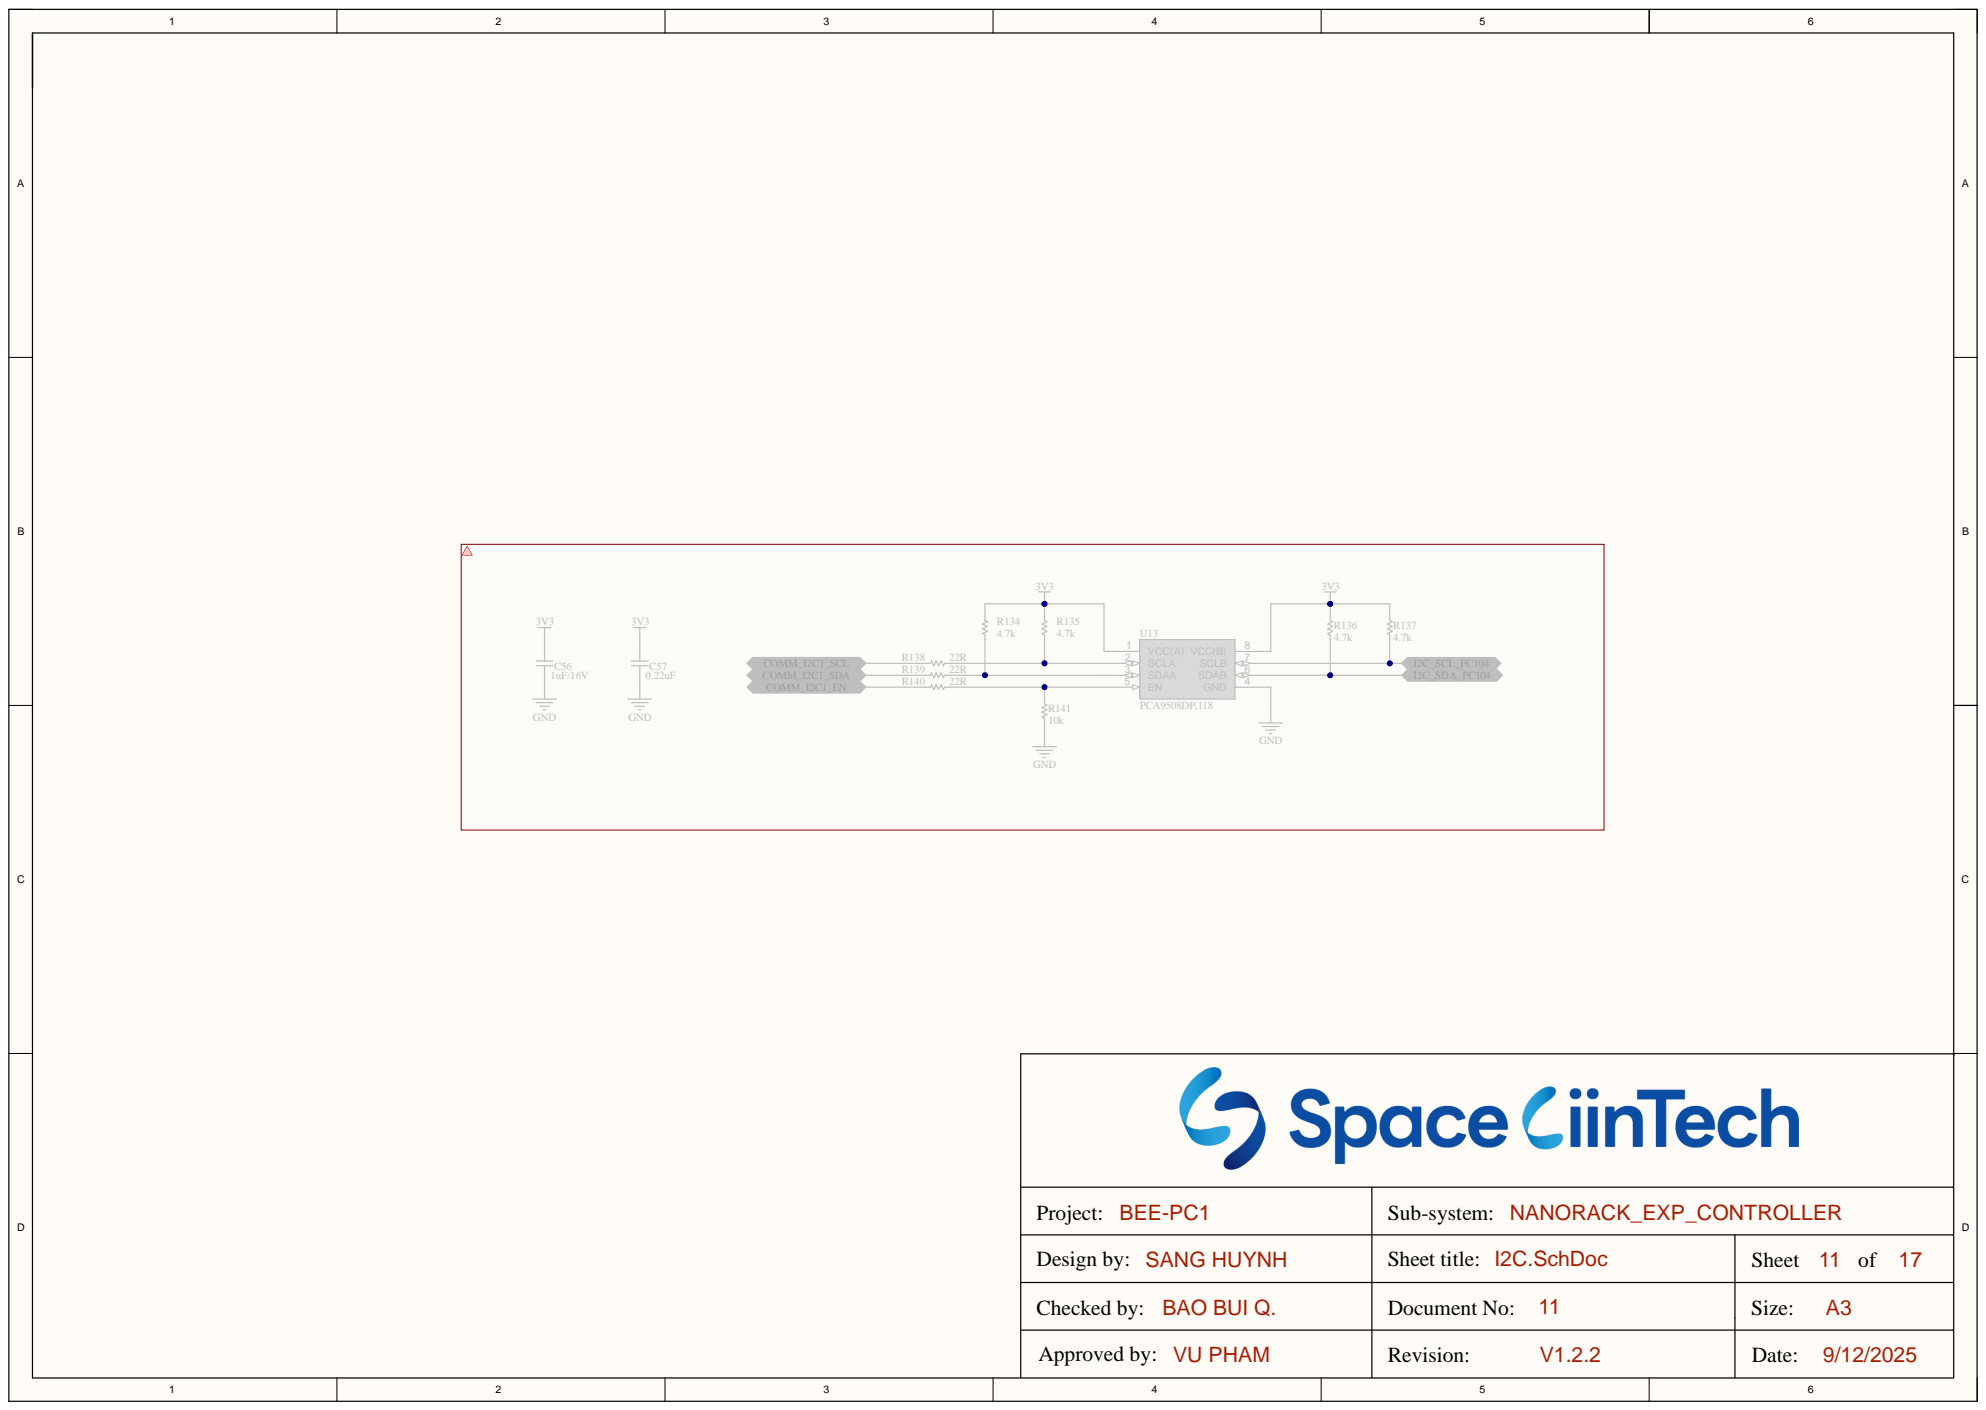
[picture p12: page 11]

Project: BEE-PC1 | Sub-system: NANORACK_EXP_CONTROLLER

Design by: SANG HUYNH | Sheet title: I2C.SchDoc | Sheet 11 of 17

Checked by: BAO BUI Q. | Document No: 11 | Size: A3

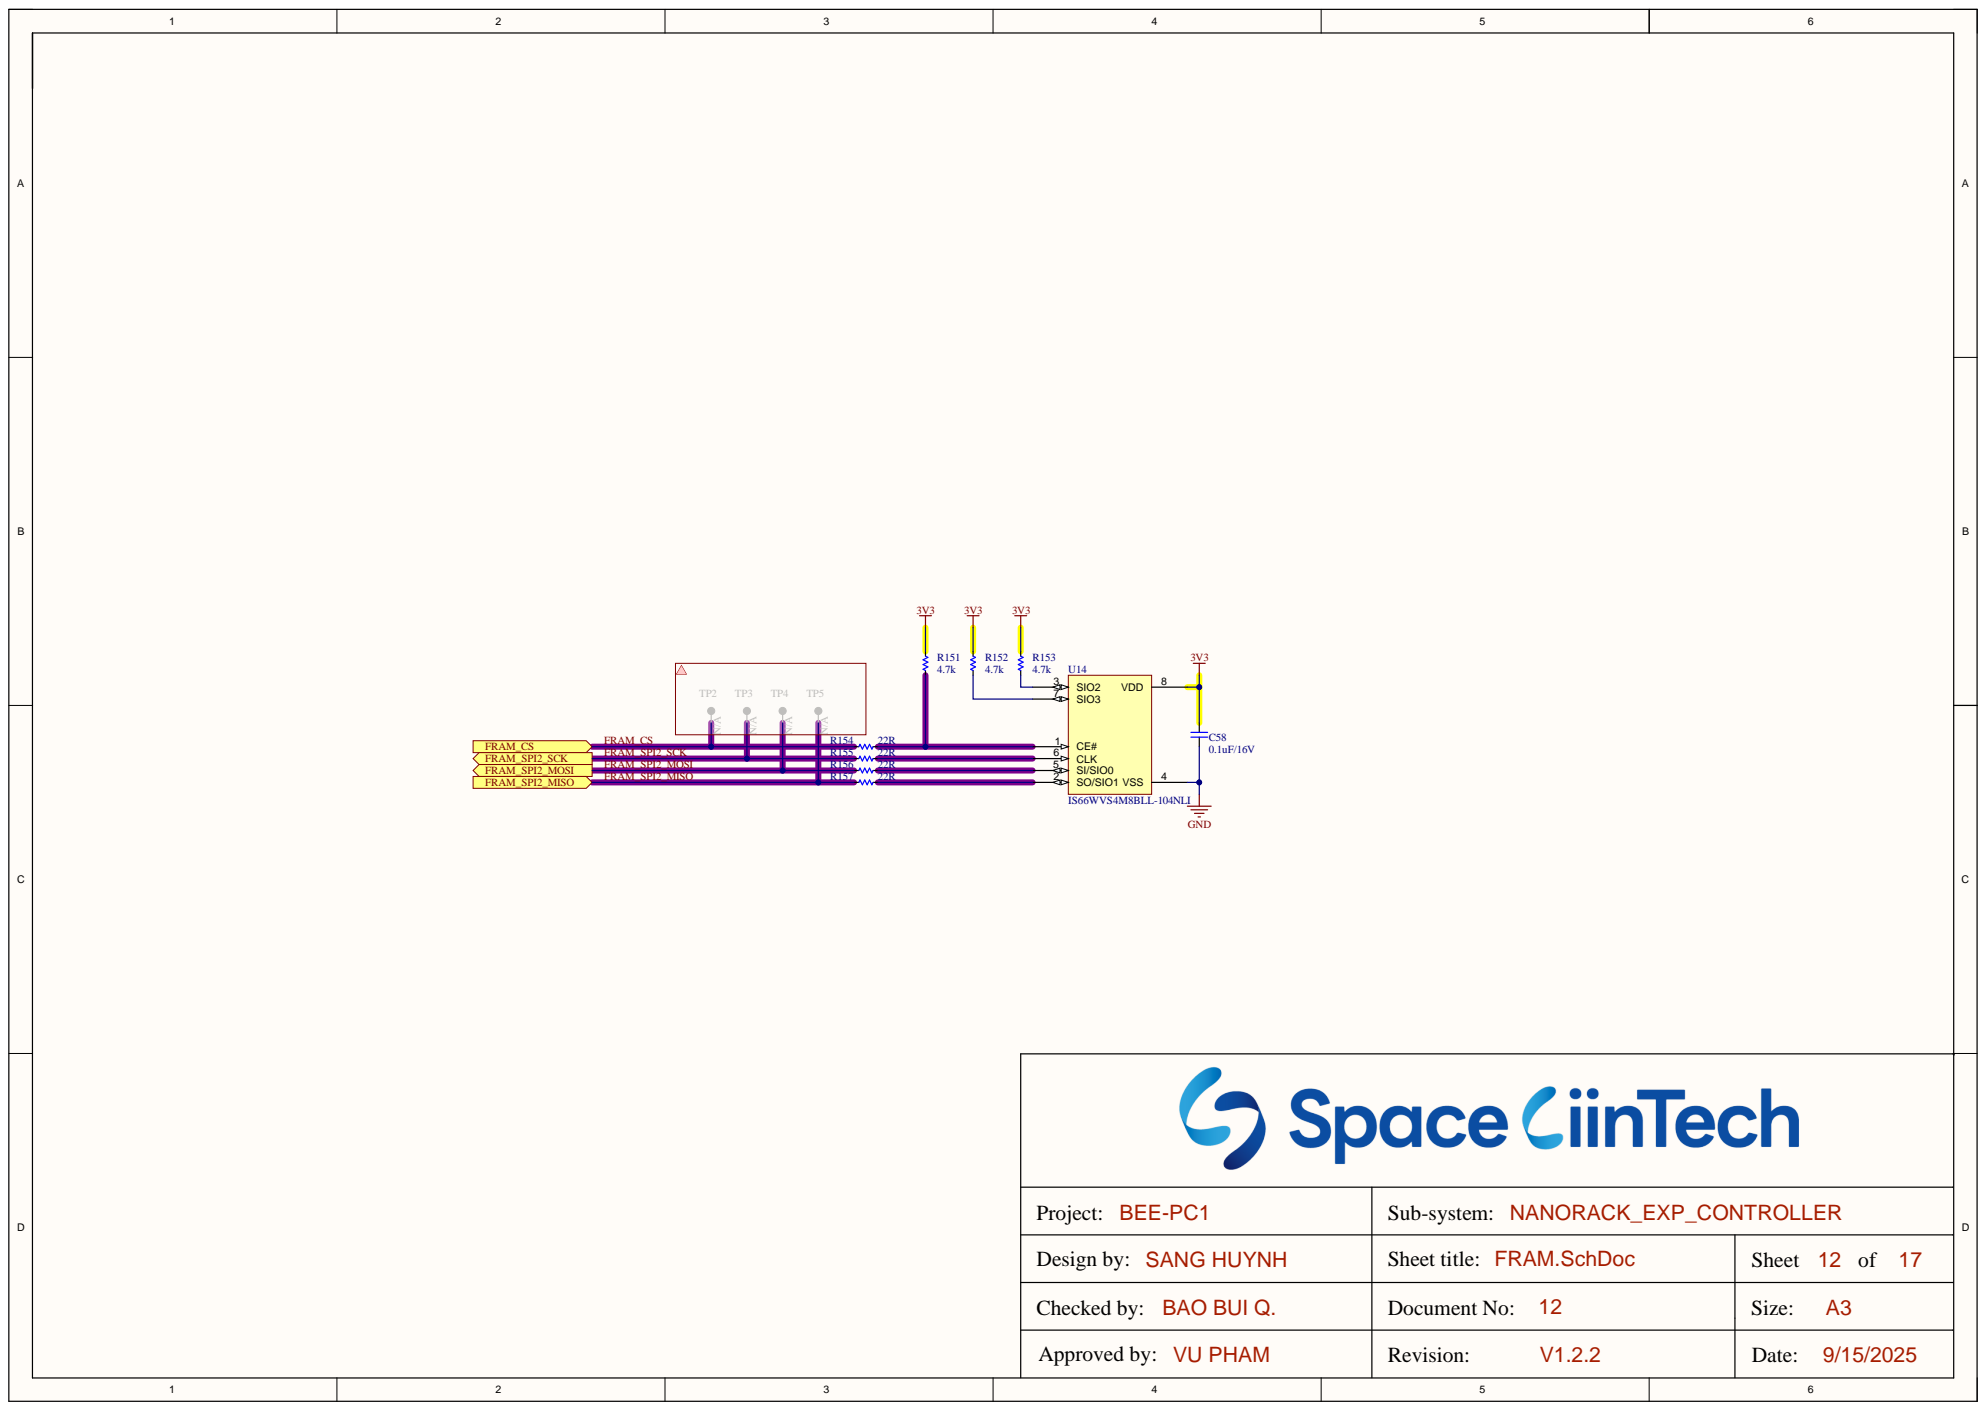
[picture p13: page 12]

Project : BEE-PC1 | Sub-system : NANORACK_EXP_CONTROLLER

Design by: SANG HUYNH | Sheet title: FRAM.SchDoc | Sheet 12 of 17

Checked by: BAO BUI Q. | Document No: 12 | Size: A3


Project: BEE-PC1 | Sub-system: NANORACK_EXP_CONTROLLER

Design by: SANG HUYNH | Sheet title: TEMP_CTRL.SchDoc | Sheet 13 of 17

Checked by: BAO BUI Q. | Document No: 13 | Size: A3


Project : BEE-PC1 | Sub-system : NANORACK_EXP_CONTROLLER

Design by: SANG HUYNH | Sheet title: WATCHDOG.SchDoc | Sheet 14 of 17

Checked by: BAO BUI Q. | Document No: 14 | Size: A3


HEADER 5X2 EXPAND FOR DEBUG

Project: BEE-PC1 | Sub-system: NANORACK_EXP_CONTROLLER

Design by: SANG HUYNH | Sheet title: DEBUG.SchDoc | Sheet 15 of 17

Checked by: BAO BUI Q. | Document No: 15 | Size: A3


VDDLDO C17

VDD50USB G17

VDD33USB F17

Project: BEE-PC1 | Sub-system: NANORACK_EXP_CONTROLLER

Design by: SANG HUYNH | Sheet title: MCU_POWER.SchDoc | Sheet 16 of 17

Checked by: BAO BUI Q. | Document No: 16 | Size: A3


Design by: SANG HUYNH | Sheet title: MCU.SchDoc | Sheet 17 of 17

Checked by: BAO BUI Q. | Document No: 17 | Size: A3



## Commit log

2025-08-05 add 01_DESIGN COMM BOARD V1, reviewed round 1
    [Arduino_Connector.SchDoc, Audio.SchDoc, CAN.SchDoc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]
2025-08-07 added full block and waiting check
    [Arduino_Connector.SchDoc, Audio.SchDoc, BOM_EXP_CAM_EXL_PHOTO.xlsx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]
2025-08-07 add watchdog file, waiting check
    [WATCHDOG.SchDoc]
2025-08-07 re-add file watchdog, waiting check
    [COMM_BOARD_V1.PrjPcb, MCU.SchDoc, MODULE_FPGA.SchDoc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]
2025-08-07 re-added fram, waiting for checking
    [CAN.SchDoc, COMM_BOARD_V1.PrjPcb, DEBUG.SchDoc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]
2025-08-07 fix file USB_OTG
    [USB_OTG.SchDoc]
2025-08-07 fixed port fram
    [FRAM.SchDoc, MCU.SchDoc]
2025-08-07 choose pin for test mcu led
    [MCU.SchDoc]
2025-08-07 fixed connect FPGA, waiting for checking
    [MCU.SchDoc, MODULE_FPGA.SchDoc]
2025-08-07 add block diagram and power tree
    [BLOCK_DIAGRAM.SchDoc, COMM_BOARD_V1.PrjPcb, CONNECTOR.SchDoc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]
2025-08-08 add footprint without footprint in sheet debug
    [BLOCK_DIAGRAM.SchDoc, CAN.SchDoc, COMM_BOARD_V1.PrjPcb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]
2025-08-09 added footprint without SDTC14 and STLink V3minie
    [1050170001.SchLib, 5040500591.PcbLib, 5040500591.SchLib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]
2025-08-09 updated all footprint without STLink v3 mine pad
    [CAN.SchDoc, COMM_BOARD_V1.PrjPcb, CONNECTOR.SchDoc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]
2025-08-12 waiting for preview 3
    [BLOCK_DIAGRAM.SchDoc, CAN.SchDoc, COMM_BOARD_V1.PrjPcb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]
2025-08-12 reup waiting for preview 3
    [MCU.SchDoc, POWER.SchDoc]
2025-08-12 add sample footprint for STLink V3minie, waiting for preview round 3
    [BLOCK_DIAGRAM.SchDoc, CAN.SchDoc, COMM_BOARD_V1.PrjPcb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]
2025-08-12 replenish footprint of header LVSD losted when imported PCB, waiting for check round 3
    [MCU.SchDoc, WATCHDOG.SchDoc, eMMC.SchDoc]
2025-08-14 verify library
    [BGA153N50P14X14_1300X1150X80N.PcbLib, CAN.SchDoc, COMM_BOARD_V1.PrjPcb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]
2025-08-14 fixed footprint of Q1
    [COMM_SCHPCB.PcbLib, MCU.SchDoc, MODULE_FPGA.SchDoc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]
2025-08-14 fixed footprint usb connector
    [COMM_SCHLIB.SchLib, COMM_SCHPCB.PcbLib, PCB3.PcbDoc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]
2025-08-15 checked sheet SDRAM, QSPI, DEBUG, USB_HS
    [COMM_BOARD_V1.PrjPcb, COMM_SCHPCB.PcbLib, DEBUG.SchDoc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]
2025-08-16 verify symbol and lib again
    [1050170001.SchLib, 5040500591.PcbLib, 5040500591.SchLib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]
2025-08-18 fix sche grid
    [COMM_BOARD_V1.PrjPcb, COMM_SCHLIB.SchLib, COMM_SCHPCB.PcbLib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]
2025-08-18 redesign schematic turn 1
    [BLOCK_DIAGRAM.SchDoc, CAN.SchDoc, COMM_BOARD_V1.PrjPcb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]
2025-08-19 redesign schematic turn 2
    [BLOCK_DIAGRAM.SchDoc, CAN.SchDoc, COMM_BOARD_V1.PrjPcb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]
2025-08-21 redesign schematic turn 3
    [COMM_BOARD_V1.PrjPcb, COMM_SCHLIB.SchLib, COMM_SCHPCB.PcbLib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]
2025-08-21 design pcb turn 1
    [COMM_BOARD_V1.PrjPcb, COMM_SCHLIB.SchLib, COMM_SCHPCB.PcbLib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]
2025-08-21 design pcb turn 2
    [COMM_SCHLIB.SchLib, COMM_SCHPCB.PcbLib, COMM_V1.PcbDoc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]
2025-08-22 export schematic.pdf
    [COMM_BOARD_V1.PrjPcb]
2025-08-27 update sche and layout
    [BLOCK_DIAGRAM.SchDoc, CAN.SchDoc, COMM_BOARD_V1.PrjPcb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]
2025-09-01 update connector's position
    [COMM_BOARD_V1.PrjPcb, COMM_SCHLIB.SchLib, COMM_SCHPCB.PcbLib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]
2025-09-01 verify schematic
    [COMM_BOARD_V1.PrjPcb, COMM_V3.PcbDoc, CONNECTOR.SchDoc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]
2025-09-02 update Gerber
    [COMM_BOARD_V1.PrjPcb, COMM_SCHLIB.SchLib, COMM_SCHPCB.PcbLib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]
2025-09-05 redesign sche and layout
    [CAN.SchDoc, COMM_BOARD_V1.PrjPcb, COMM_SCHLIB.SchLib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]
2025-09-13 PCB done
    [COMM_V3.PcbDoc]
2025-09-14 update Sche, PCB, BOM | Release
    [BOM_EXP_CAM_EXL_PHOTO.xlsx, CAN.SchDoc, COMM_BOARD_V1.PrjPcb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]
2025-09-15 verify 1
    [COMM_BOARD_V1.PrjPcb, COMM_V100_BOM.xlsx, COMM_V3.PcbDoc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]
2025-09-15 verify 2
    [COMM_V3.PcbDoc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]
2025-09-15 update pcb with new stackup
    [COMM_BOARD_V1.PrjPcb, COMM_SCHPCB.PcbLib, COMM_V3.PcbDoc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]
2025-09-18 update SMT
    [COMM_BOARD_V1.PrjPcb, COMM_SCHPCB.PcbLib, PAY-IF_R100.step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]
